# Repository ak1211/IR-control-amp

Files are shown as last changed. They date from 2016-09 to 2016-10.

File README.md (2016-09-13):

# IR-control-amp

## Overview
Infra Red remote control amplifier firmware on atmega328p

## Description
このソフトウエアはatmega328p使用  
赤外線リモコンコントロールヘッドホンアンプ基板Rev: A2.x用  
組込みファームウエアです。

## Requirements
Atmel Studio 7 (Version: 7.0.594 - )
© 2015 Atmel Corp.
All rights reserved.

## Compile and Link
Atmel Studio 7で[solution file](https://github.com/ak1211/IR-control-amp/blob/master/AudioAmpApplication/AudioAmpApplication.atsln)
を開いてコンパイル＆リンクを行ってください。

## License
[MIT](https://github.com/ak1211/IR-control-amp/blob/master/LICENSE)

## Author
[ak1211](https://github.com/ak1211/) - [blog](https://ak1211.com/index.php)

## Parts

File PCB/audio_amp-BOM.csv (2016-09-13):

Reference | Value | Footprint | Datasheet
L1 | 220u | Choke_SMD:Choke_SMD_10.4x10.4_H4.8
L2 | 220u | Choke_SMD:Choke_SMD_10.4x10.4_H4.8
U1 | NJU7223DL1 | Transistors_SMD:sot428
F1 | PolySW 1.85A | Fuse_Holders_and_Fuses:Fuse_TE5_Littlefuse-395Series
CON1 | BARREL_JACK | Connect:BARREL_JACK
U3 | FDS4935 | Housings_SOIC:SOIC-8_3.9x4.9mm_Pitch1.27mm
U2 | NDS9936 | Housings_SOIC:SOIC-8_3.9x4.9mm_Pitch1.27mm
U4 | MCWI03_12D05 | mylib:MINMAX_MCWI03-12x
Q1 | 2SK2411 | Transistors_SMD:sot404
C3 | 8200u | Capacitors_ThroughHole:C_Radial_D18_L36_P7.5
C1 | 220u | Capacitors_SMD:c_elec_10x10.5
C2 | 47u | Capacitors_SMD:c_elec_10x10.5
C4 | 22u(tantalum) | Capacitors_Tantalum_SMD:TantalC_SizeA_EIA-3216_HandSoldering
C5 | 22u(tantalum) | Capacitors_Tantalum_SMD:TantalC_SizeA_EIA-3216_HandSoldering
C6 | 22u(tantalum) | Capacitors_Tantalum_SMD:TantalC_SizeA_EIA-3216_HandSoldering
C7 | 22u(tantalum) | Capacitors_Tantalum_SMD:TantalC_SizeA_EIA-3216_HandSoldering
D1 | LED | LEDs:LED-0805
P1 | AMP_POWER | Sockets_MOLEX_KK-System:Socket_MOLEX-KK-RM3-96mm_Lock_2pin_straight
R1 | 10 | Resistors_SMD:R_0805_HandSoldering
R2 | 10k | Resistors_SMD:R_0805_HandSoldering
R3 | 33k | Resistors_SMD:R_0805_HandSoldering
R4 | 33(2W) | Resistors_ThroughHole:Resistor_Horizontal_RM20mm
R5 | 10 | Resistors_SMD:R_0805_HandSoldering
R6 | 10k | Resistors_SMD:R_0805_HandSoldering
R7 | 33k | Resistors_SMD:R_0805_HandSoldering
R8 | 4.7k | Resistors_SMD:R_0805_HandSoldering
C30 | 22u(tantalum) | Capacitors_Tantalum_SMD:TantalC_SizeA_EIA-3216_HandSoldering
C29 | 22u(tantalum) | Capacitors_Tantalum_SMD:TantalC_SizeA_EIA-3216_HandSoldering
C32 | 0.1u | Capacitors_SMD:C_0805_HandSoldering
C31 | 0.1u | Capacitors_SMD:C_0805_HandSoldering
C33 | 0.1u | Capacitors_SMD:C_0805_HandSoldering
U10 | NDS9936 | Housings_SOIC:SOIC-8_3.9x4.9mm_Pitch1.27mm
R46 | 33k | Resistors_SMD:R_0805_HandSoldering
U8 | LME49600 | mylib:LME49600
J3 | PHONE OUT | toragi_201305:AJ-1780
J1 | 1ch IN | toragi_201305:AJ-1780
J2 | 2ch IN | toragi_201305:AJ-1780
U7 | LM1972 | Housings_SOIC:SOIC-20_7.5x12.8mm_Pitch1.27mm
C22 | 0.1u | Capacitors_SMD:C_0805_HandSoldering
C15 | 1u(film) | Capacitors_SMD:C_1206_HandSoldering
C16 | 1u(film) | Capacitors_SMD:C_1206_HandSoldering
U9 | LME49600 | mylib:LME49600
C18 | 1u(film) | Capacitors_SMD:C_1206_HandSoldering
C19 | 1u(film) | Capacitors_SMD:C_1206_HandSoldering
C14 | 1u(film) | Capacitors_SMD:C_1206_HandSoldering
C8 | 1u(film) | Capacitors_SMD:C_1206_HandSoldering
C9 | 1u(film) | Capacitors_SMD:C_1206_HandSoldering
C17 | 1u(film) | Capacitors_SMD:C_1206_HandSoldering
C12 | 1u(film) | Capacitors_SMD:C_1206_HandSoldering
C13 | 1u(film) | Capacitors_SMD:C_1206_HandSoldering
C20 | 1u(film) | Capacitors_SMD:C_1206_HandSoldering
C21 | 1u(film) | Capacitors_SMD:C_1206_HandSoldering
G1 | GND_SUMMING_PT | mylib:GND_SUMMING_PT
C11 | open | Capacitors_SMD:C_1206_HandSoldering
C10 | open | Capacitors_SMD:C_1206_HandSoldering
D2 | 02CZ3.3(3.3V) | mylib_legacy:SC-59
D3 | 02CZ3.3(3.3V) | mylib_legacy:SC-59
P2 | OUT ch.L | Sockets_MOLEX_KK-System:Socket_MOLEX-KK-RM2-54mm_Lock_2pin_straight
P3 | OUT ch.R | Sockets_MOLEX_KK-System:Socket_MOLEX-KK-RM2-54mm_Lock_2pin_straight
R9 | open | Resistors_SMD:R_0805_HandSoldering
R10 | open | Resistors_SMD:R_0805_HandSoldering
R18 | 100k | Resistors_SMD:R_0805_HandSoldering
R22 | 10 | Resistors_SMD:R_0805_HandSoldering
R23 | 10k | Resistors_SMD:R_0805_HandSoldering
R24 | 10k | Resistors_SMD:R_0805_HandSoldering
R26 | 10k | Resistors_SMD:R_0805_HandSoldering
R25 | 10k | Resistors_SMD:R_0805_HandSoldering
R27 | 10k | Resistors_SMD:R_0805_HandSoldering
R11 | 1k | Resistors_SMD:R_0805_HandSoldering
R21 | 1k | Resistors_SMD:R_0805_HandSoldering
R19 | 1k | Resistors_SMD:R_0805_HandSoldering
R13 | 1M | Resistors_SMD:R_0805_HandSoldering
R14 | 1M | Resistors_SMD:R_0805_HandSoldering
R20 | 1k | Resistors_SMD:R_0805_HandSoldering
R17 | 1k | Resistors_SMD:R_0805_HandSoldering
R12 | 1k | Resistors_SMD:R_0805_HandSoldering
R15 | 1M | Resistors_SMD:R_0805_HandSoldering
R16 | 1M | Resistors_SMD:R_0805_HandSoldering
D4 | 1N4148W1 | Diodes_SMD:SOD-123
D5 | 1N4148W1 | Diodes_SMD:SOD-123
D6 | 1N4148W1 | Diodes_SMD:SOD-123
inputRLY1 | G5V2 | mylib:G5V-2
C27 | 1u(film) | Capacitors_SMD:C_1206_HandSoldering
C28 | 1u(film) | Capacitors_SMD:C_1206_HandSoldering
JP2 | Jumper_NC_Small | Connect:GS2
JP3 | Jumper_NC_Small | Connect:GS2
U11 | LMC6482
U5 | LME49720
U6 | LME49720
Q2 | 8MHz | mylib:CERALOCK
U14 | PL-IRM2161 | mylib:PL-IRM2161
U18 | SO1602AWYB-UC-WB | Display:WC1602A
RE1 | R_ENC_SW_RGB_LED | mylib:EC12PLRGBSDHF
U13 | NDS9936 | Housings_SOIC:SOIC-8_3.9x4.9mm_Pitch1.27mm
U12 | NDS9936 | Housings_SOIC:SOIC-8_3.9x4.9mm_Pitch1.27mm
U17 | FDS4935 | Housings_SOIC:SOIC-8_3.9x4.9mm_Pitch1.27mm
C23 | 0.1u | Capacitors_SMD:C_0805_HandSoldering
C24 | 0.1u | Capacitors_SMD:C_0805_HandSoldering
C26 | 2.2u | Capacitors_SMD:C_1206_HandSoldering
U15 | TLP121 | Opto-Devices:Optocoupler_SMD_HandSoldering_KPC357_LTV35x_PC357_SingleChannel
U16 | TLP121 | Opto-Devices:Optocoupler_SMD_HandSoldering_KPC357_LTV35x_PC357_SingleChannel
IC1 | ATMEGA328P-P | Housings_DIP:DIP-28_W7.62mm_LongPads
P4 | AVRISP | mylib:AVRISP_Angled
SW1 | RESET | mylib:ALPS_TACT_SW_SKHHL
P7 | STBY | Sockets_MOLEX_KK-System:Socket_MOLEX-KK-RM2-54mm_Lock_3pin_straight
P8 | MUTE | Sockets_MOLEX_KK-System:Socket_MOLEX-KK-RM2-54mm_Lock_3pin_straight
P5 | DISPLAY | Sockets_MOLEX_KK-System:Socket_MOLEX-KK-RM2-54mm_Lock_4pin_straight
P6 | CONN_01X04 | Sockets_MOLEX_KK-System:Socket_MOLEX-KK-RM2-54mm_Lock_4pin_straight
R28 | 1k | Resistors_SMD:R_0805_HandSoldering
R31 | 1k | Resistors_SMD:R_0805_HandSoldering
R34 | 1.2k | Resistors_SMD:R_0805_HandSoldering
R29 | 10k | Resistors_SMD:R_0805_HandSoldering
R30 | 10 | Resistors_SMD:R_0805_HandSoldering
R32 | 10k | Resistors_SMD:R_0805_HandSoldering
R33 | 10 | Resistors_SMD:R_0805_HandSoldering
R35 | 10k | Resistors_SMD:R_0805_HandSoldering
R36 | 10 | Resistors_SMD:R_0805_HandSoldering
R37 | 10k | Resistors_SMD:R_0805_HandSoldering
R40 | 330 | Resistors_SMD:R_0805_HandSoldering
R41 | 330 | Resistors_SMD:R_0805_HandSoldering
R44 | 10k | Resistors_SMD:R_0805_HandSoldering
R45 | 10k | Resistors_SMD:R_0805_HandSoldering
R43 | 10k | Resistors_SMD:R_0805_HandSoldering
R42 | 10 | Resistors_SMD:R_0805_HandSoldering
R38 | 4.7k | Resistors_SMD:R_0805_HandSoldering
R39 | 4.7k | Resistors_SMD:R_0805_HandSoldering
C25 | 0.1u | Capacitors_SMD:C_0805_HandSoldering

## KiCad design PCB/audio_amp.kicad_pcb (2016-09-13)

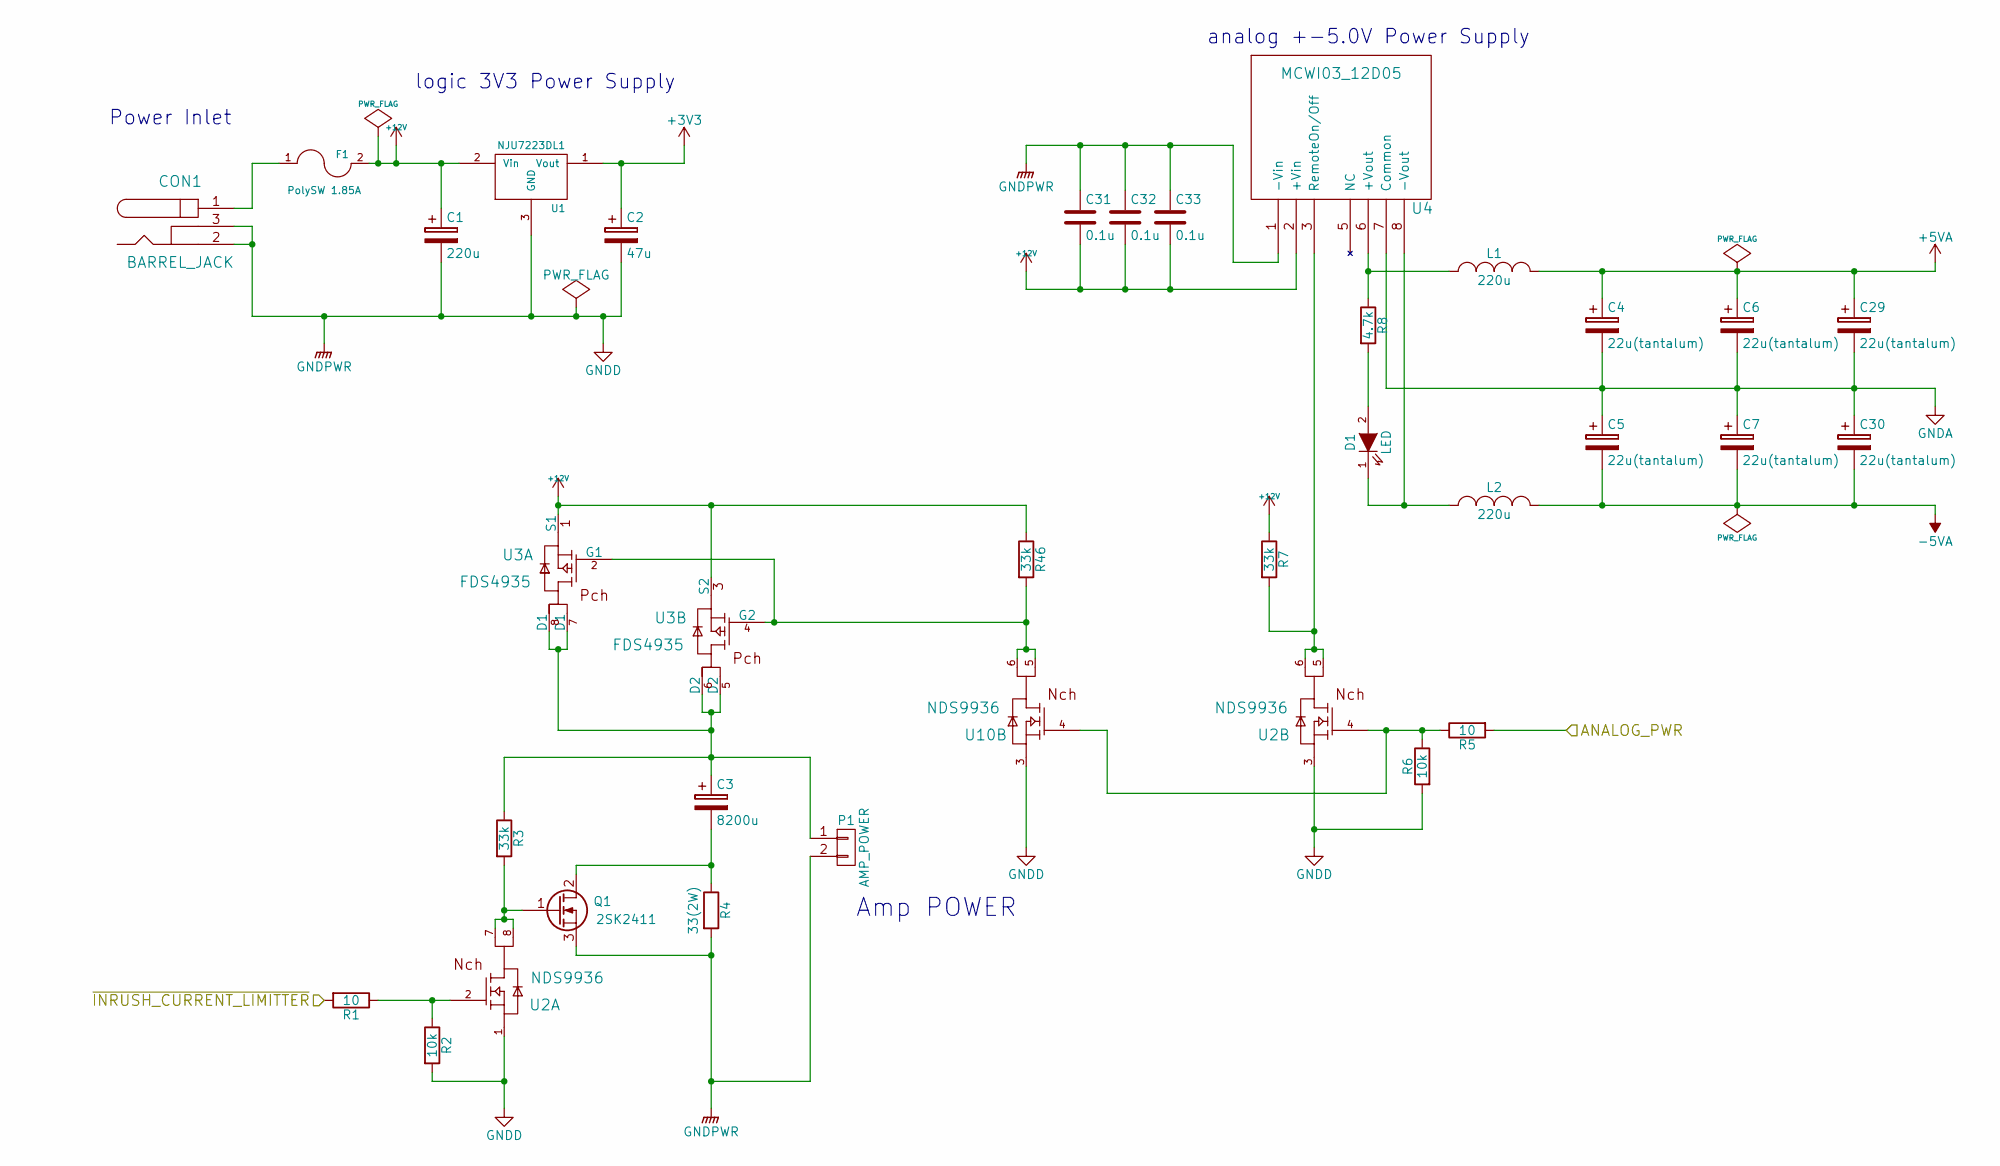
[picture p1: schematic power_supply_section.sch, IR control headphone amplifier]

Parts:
C1: 220u; c_elec_10x10.5
C2: 47u; c_elec_10x10.5
C3: 8200u; C_Radial_D18_L36_P7.5
C4, C5, C6, C7, C29, C30: 22u(tantalum); TantalC_SizeA_EIA-3216_HandSoldering
C31, C32, C33: 0.1u; C_0805_HandSoldering
CON1: BARREL_JACK
D1: LED; LED-0805
F1: PolySW 1.85A; Fuse_TE5_Littlefuse-395Series
L1, L2: 220u; Choke_SMD_10.4x10.4_H4.8
P1: AMP_POWER; Socket_MOLEX-KK-RM3-96mm_Lock_2pin_straight
Q1: 2SK2411; sot404
R1, R5: 10; R_0805_HandSoldering
R2, R6: 10k; R_0805_HandSoldering
R3, R7, R46: 33k; R_0805_HandSoldering
R4: 33(2W); Resistor_Horizontal_RM20mm
R8: 4.7k; R_0805_HandSoldering
U1: NJU7223DL1; sot428
U2, U10: NDS9936; SOIC-8_3.9x4.9mm_Pitch1.27mm
U3: FDS4935; SOIC-8_3.9x4.9mm_Pitch1.27mm
U4: MCWI03_12D05; MINMAX_MCWI03-12x

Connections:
+3V3: C2.1, U1.1 (Vout); also elsewhere on the board
+5VA: C4.1, C6.1, C29.1, L1.2; also elsewhere on the board
+12V: C1.1, C31.2, C32.2, C33.2, F1.2, R7.1, R46.1, U1.2 (Vin), U3.1 (S1), U3.3 (S2), U4.2 (+Vin); also elsewhere on the board
-5VA: C5.2, C7.2, C30.2, L2.2; also elsewhere on the board
/controller_section/ANALOG_PWR: R5.2; also elsewhere on the board
/controller_section/~INRUSH_CURRENT_LIMITTER: R1.2; also elsewhere on the board
GNDA: C4.2, C5.1, C6.2, C7.1, C29.2, C30.1, U4.7 (Common); also elsewhere on the board
GNDD: C1.2, C2.2, C31.1, C32.1, C33.1, CON1.2, CON1.3, P1.2, Q1.3 (S), R2.2, R4.2, R6.2, U1.3 (GND), U2.1, U2.3, U4.1 (-Vin), U10.3; also elsewhere on the board
unnamed: C3.1, P1.1, R3.1, U3.5 (D2), U3.6 (D2), U3.7 (D1), U3.8 (D1)
unnamed: C3.2, Q1.2 (D), R4.1
unnamed: CON1.1, F1.1
unnamed: D1.1 (K), L2.1, U4.8 (-Vout)
unnamed: D1.2 (A), R8.2
unnamed: L1.1, R8.1, U4.6 (+Vout)
unnamed: Q1.1 (G), R3.2, U2.7, U2.8
unnamed: R1.1, R2.1, U2.2
unnamed: R5.1, R6.1, U2.4, U10.4
unnamed: R7.2, U2.5, U2.6, U4.3 (RemoteOn/Off)
unnamed: R46.2, U3.2 (G1), U3.4 (G2), U10.5, U10.6

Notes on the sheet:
analog +-5.0V Power Supply
Power Inlet
logic 3V3 Power Supply
Amp POWER

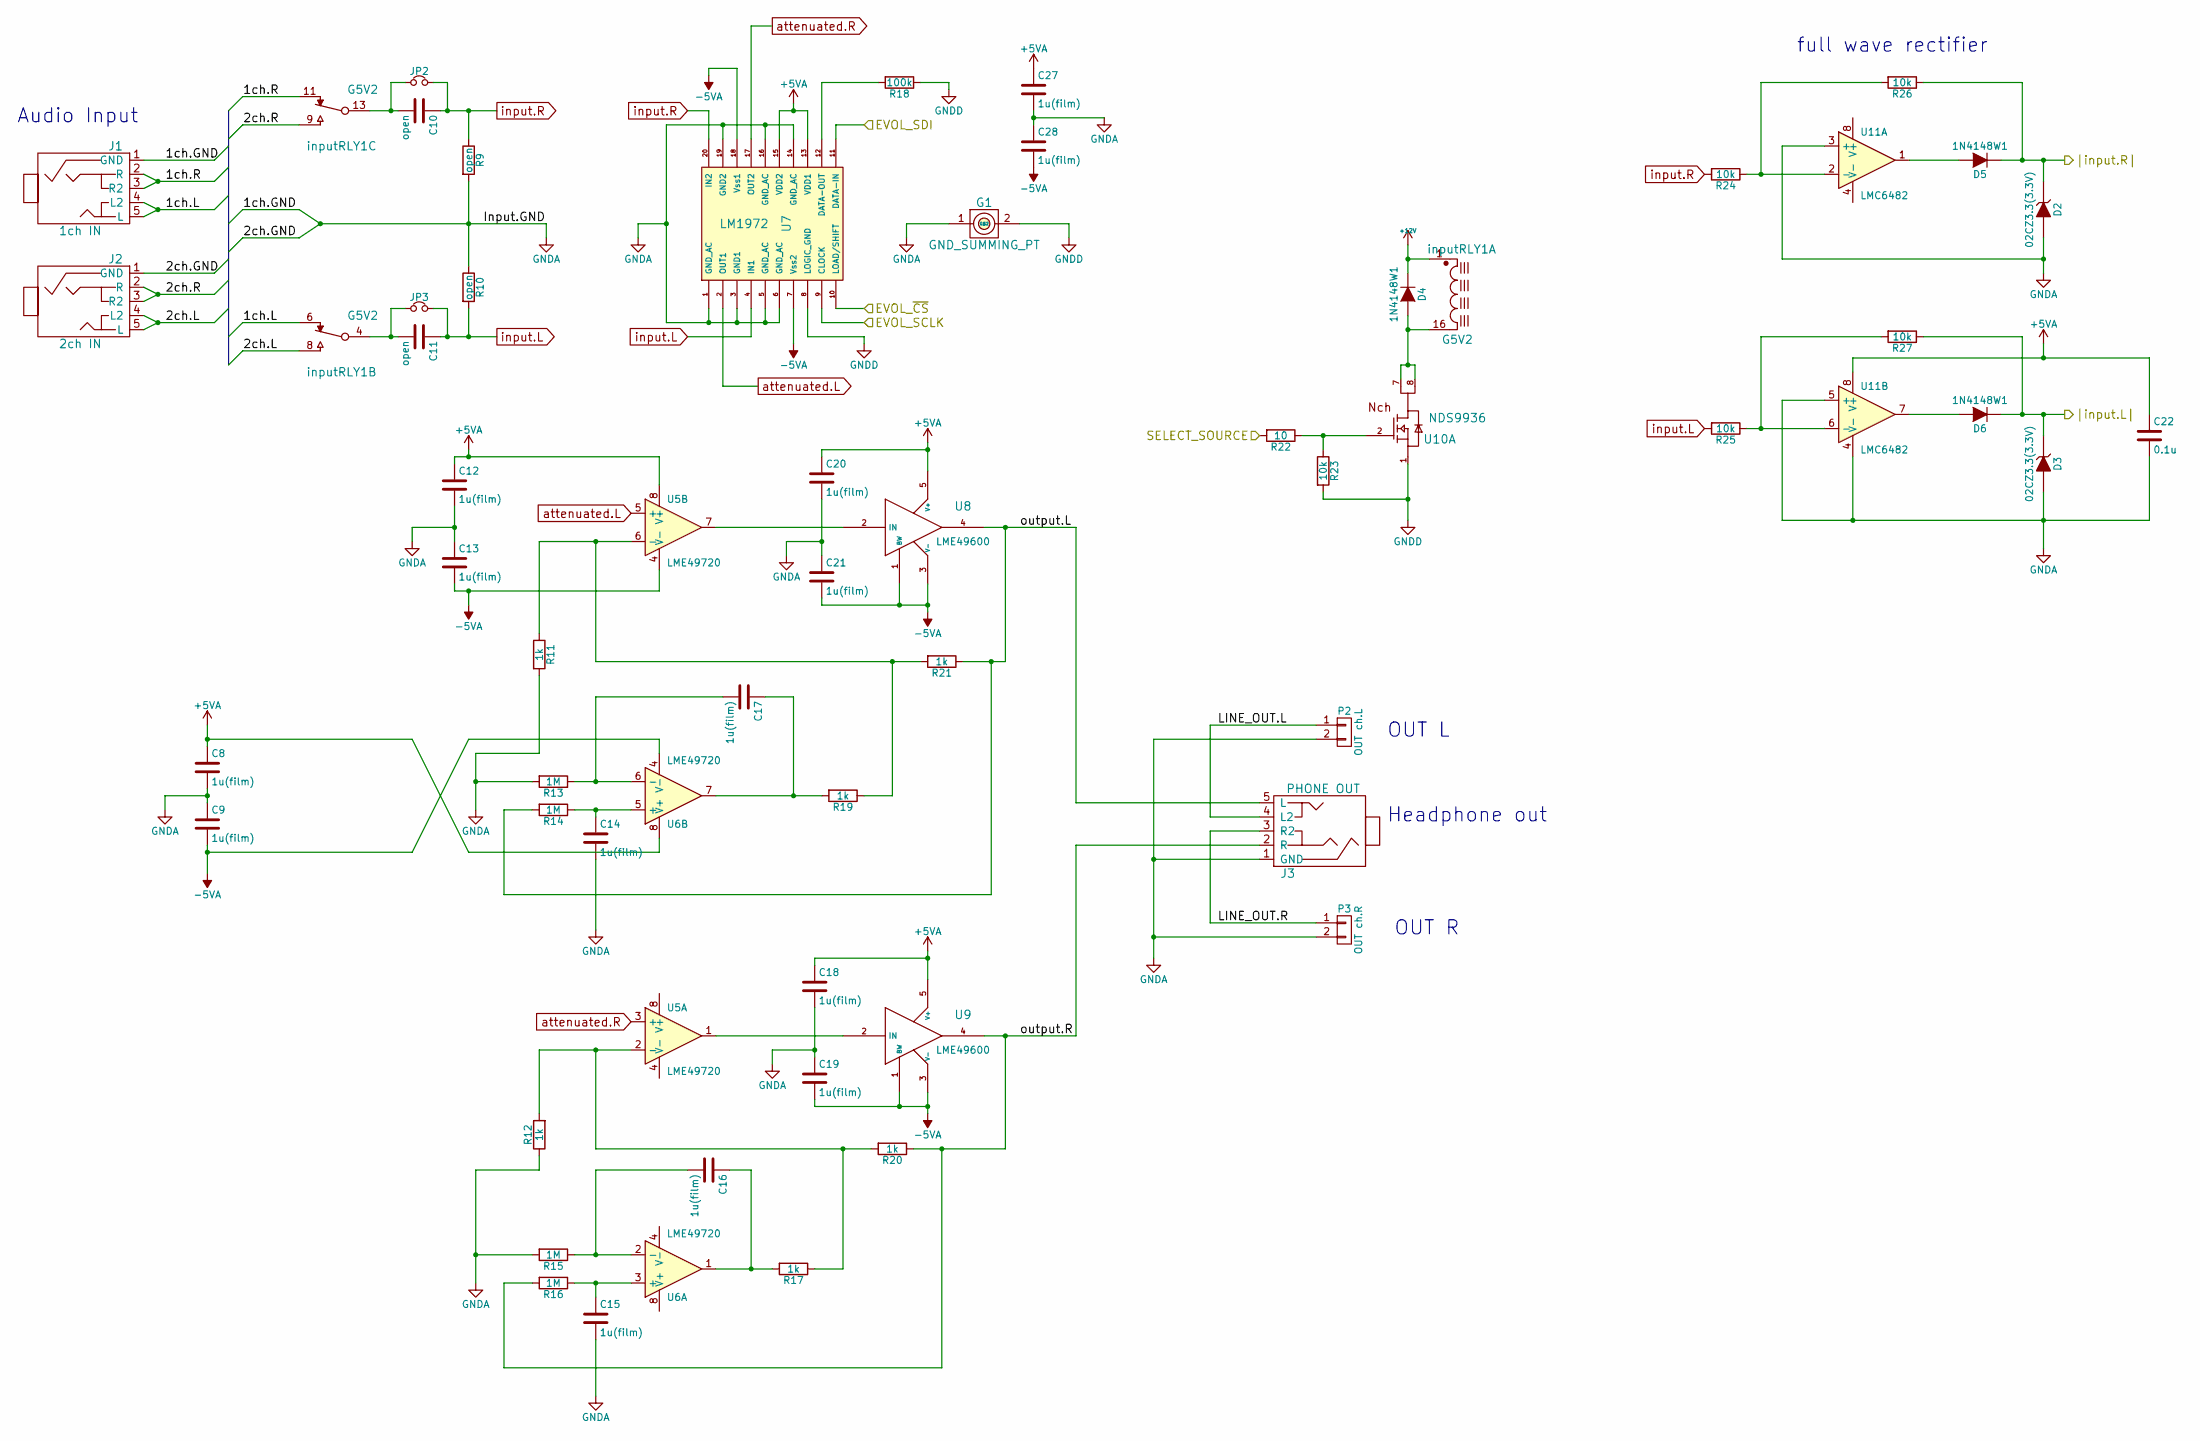
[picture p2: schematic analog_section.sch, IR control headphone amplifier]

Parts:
C8, C9, C12, C13, C14, C15, C16, C17, C18, C19, C20, C21, C27, C28: 1u(film); C_1206_HandSoldering
C10, C11: open; C_1206_HandSoldering
C22: 0.1u; C_0805_HandSoldering
D2, D3: 02CZ3.3(3.3V); SC-59
D4, D5, D6: 1N4148W1; SOD-123
G1: GND_SUMMING_PT
J1: 1ch IN; AJ-1780
J2: 2ch IN; AJ-1780
J3: PHONE OUT; AJ-1780
JP2, JP3: Jumper_NC_Small; GS2
P2: OUT ch.L; Socket_MOLEX-KK-RM2-54mm_Lock_2pin_straight
P3: OUT ch.R; Socket_MOLEX-KK-RM2-54mm_Lock_2pin_straight
R9, R10: open; R_0805_HandSoldering
R11, R12, R17, R19, R20, R21: 1k; R_0805_HandSoldering
R13, R14, R15, R16: 1M; R_0805_HandSoldering
R18: 100k; R_0805_HandSoldering
R22: 10; R_0805_HandSoldering
R23, R24, R25, R26, R27: 10k; R_0805_HandSoldering
U5, U6: LME49720
U7: LM1972; SOIC-20_7.5x12.8mm_Pitch1.27mm
U8, U9: LME49600
U10: NDS9936; SOIC-8_3.9x4.9mm_Pitch1.27mm
U11: LMC6482
inputRLY1: G5V2; G5V-2

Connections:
+5VA: C8.1, C12.1, C18.1, C20.1, C22.1, C27.1, U5.8 (V+), U6.8 (V+), U7.13 (VDD1), U7.15 (VDD2), U8.5 (V+), U9.5 (V+), U11.8 (V+); also elsewhere on the board
+12V: D4.1 (K), inputRLY1.1; also elsewhere on the board
-5VA: C9.2, C13.2, C19.2, C21.2, C28.2, U5.4 (V-), U6.4 (V-), U7.7 (Vss2), U7.18 (Vss1), U8.1 (BW), U8.3 (V-), U9.1 (BW), U9.3 (V-); also elsewhere on the board
/analog_section/1ch.L: J1.4 (L2), J1.5 (L), inputRLY1.6
/analog_section/1ch.R: J1.2 (R), J1.3 (R2), inputRLY1.11
/analog_section/2ch.L: J2.4 (L2), J2.5 (L), inputRLY1.8
/analog_section/2ch.R: J2.2 (R), J2.3 (R2), inputRLY1.9
/analog_section/EVOL_SCLK: U7.9 (CLOCK); also elsewhere on the board
/analog_section/EVOL_SDI: U7.11 (DATA-IN); also elsewhere on the board
/analog_section/EVOL_~CS: U7.10 (LOAD/SHIFT); also elsewhere on the board
/analog_section/LINE_OUT.L: J3.4 (L2), P2.1
/analog_section/LINE_OUT.R: J3.3 (R2), P3.1
/analog_section/SELECT_SOURCE: R22.2; also elsewhere on the board
/analog_section/output.L: J3.5 (L), R14.2, R21.1, U8.4
/analog_section/output.R: J3.2 (R), R16.2, R20.1, U9.4
/analog_section/|input.L|: D3.1 (K), D6.1 (K), R27.1; also elsewhere on the board
/analog_section/|input.R|: D2.1 (K), D5.1 (K), R26.1; also elsewhere on the board
GNDA: C8.2, C9.1, C12.2, C13.1, C14.2, C15.2, C18.2, C19.1, C20.2, C21.1, C22.2, C27.2, C28.1, D2.2 (A), D3.2 (A), G1.1 (G1), J1.1 (GND), J2.1 (GND), J3.1 (GND), P2.2, P3.2, R9.2, R10.1, R11.2, R12.1, R13.2, R15.2, U7.1 (GND_AC), U7.3 (GND1), U7.5 (GND_AC), U7.6 (GND_AC), U7.14 (GND_AC), U7.16 (GND_AC), U7.19 (GND2), U11.3 (+), U11.4 (V-), U11.5 (+); also elsewhere on the board
GNDD: G1.2 (G2), R18.1, R23.2, U7.8 (LOGIC_GND), U10.1; also elsewhere on the board
unnamed: C10.2, JP2.1, inputRLY1.13
unnamed: C11.2, JP3.1, inputRLY1.4
unnamed: C14.1, R14.1, U6.5 (+)
unnamed: C15.1, R16.1, U6.3 (+)
unnamed: C16.1, R17.2, U6.1
unnamed: C16.2, R15.1, U6.2 (-)
unnamed: C17.1, R19.2, U6.7
unnamed: C17.2, R13.1, U6.6 (-)
unnamed: D4.2 (A), U10.7, U10.8, inputRLY1.16
unnamed: D5.2 (A), U11.1
unnamed: D6.2 (A), U11.7
unnamed: R11.1, R19.1, R21.2, U5.6 (-)
unnamed: R12.2, R17.1, R20.2, U5.2 (-)
unnamed: R18.2, U7.12 (DATA-OUT)
unnamed: R22.1, R23.1, U10.2
unnamed: R24.1, R26.2, U11.2 (-)
unnamed: R25.1, R27.2, U11.6 (-)
unnamed: U5.1, U9.2 (IN)
unnamed: U5.7, U8.2 (IN)
attenuated.L: U5.5 (+), U7.2 (OUT1)
attenuated.R: U5.3 (+), U7.17 (OUT2)
input.L: C11.1, JP3.2, R10.2, R25.2, U7.4 (IN1)
input.R: C10.1, JP2.2, R9.1, R24.2, U7.20 (IN2)

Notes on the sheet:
OUT R
Audio Input
Headphone out
full wave rectifier
OUT L

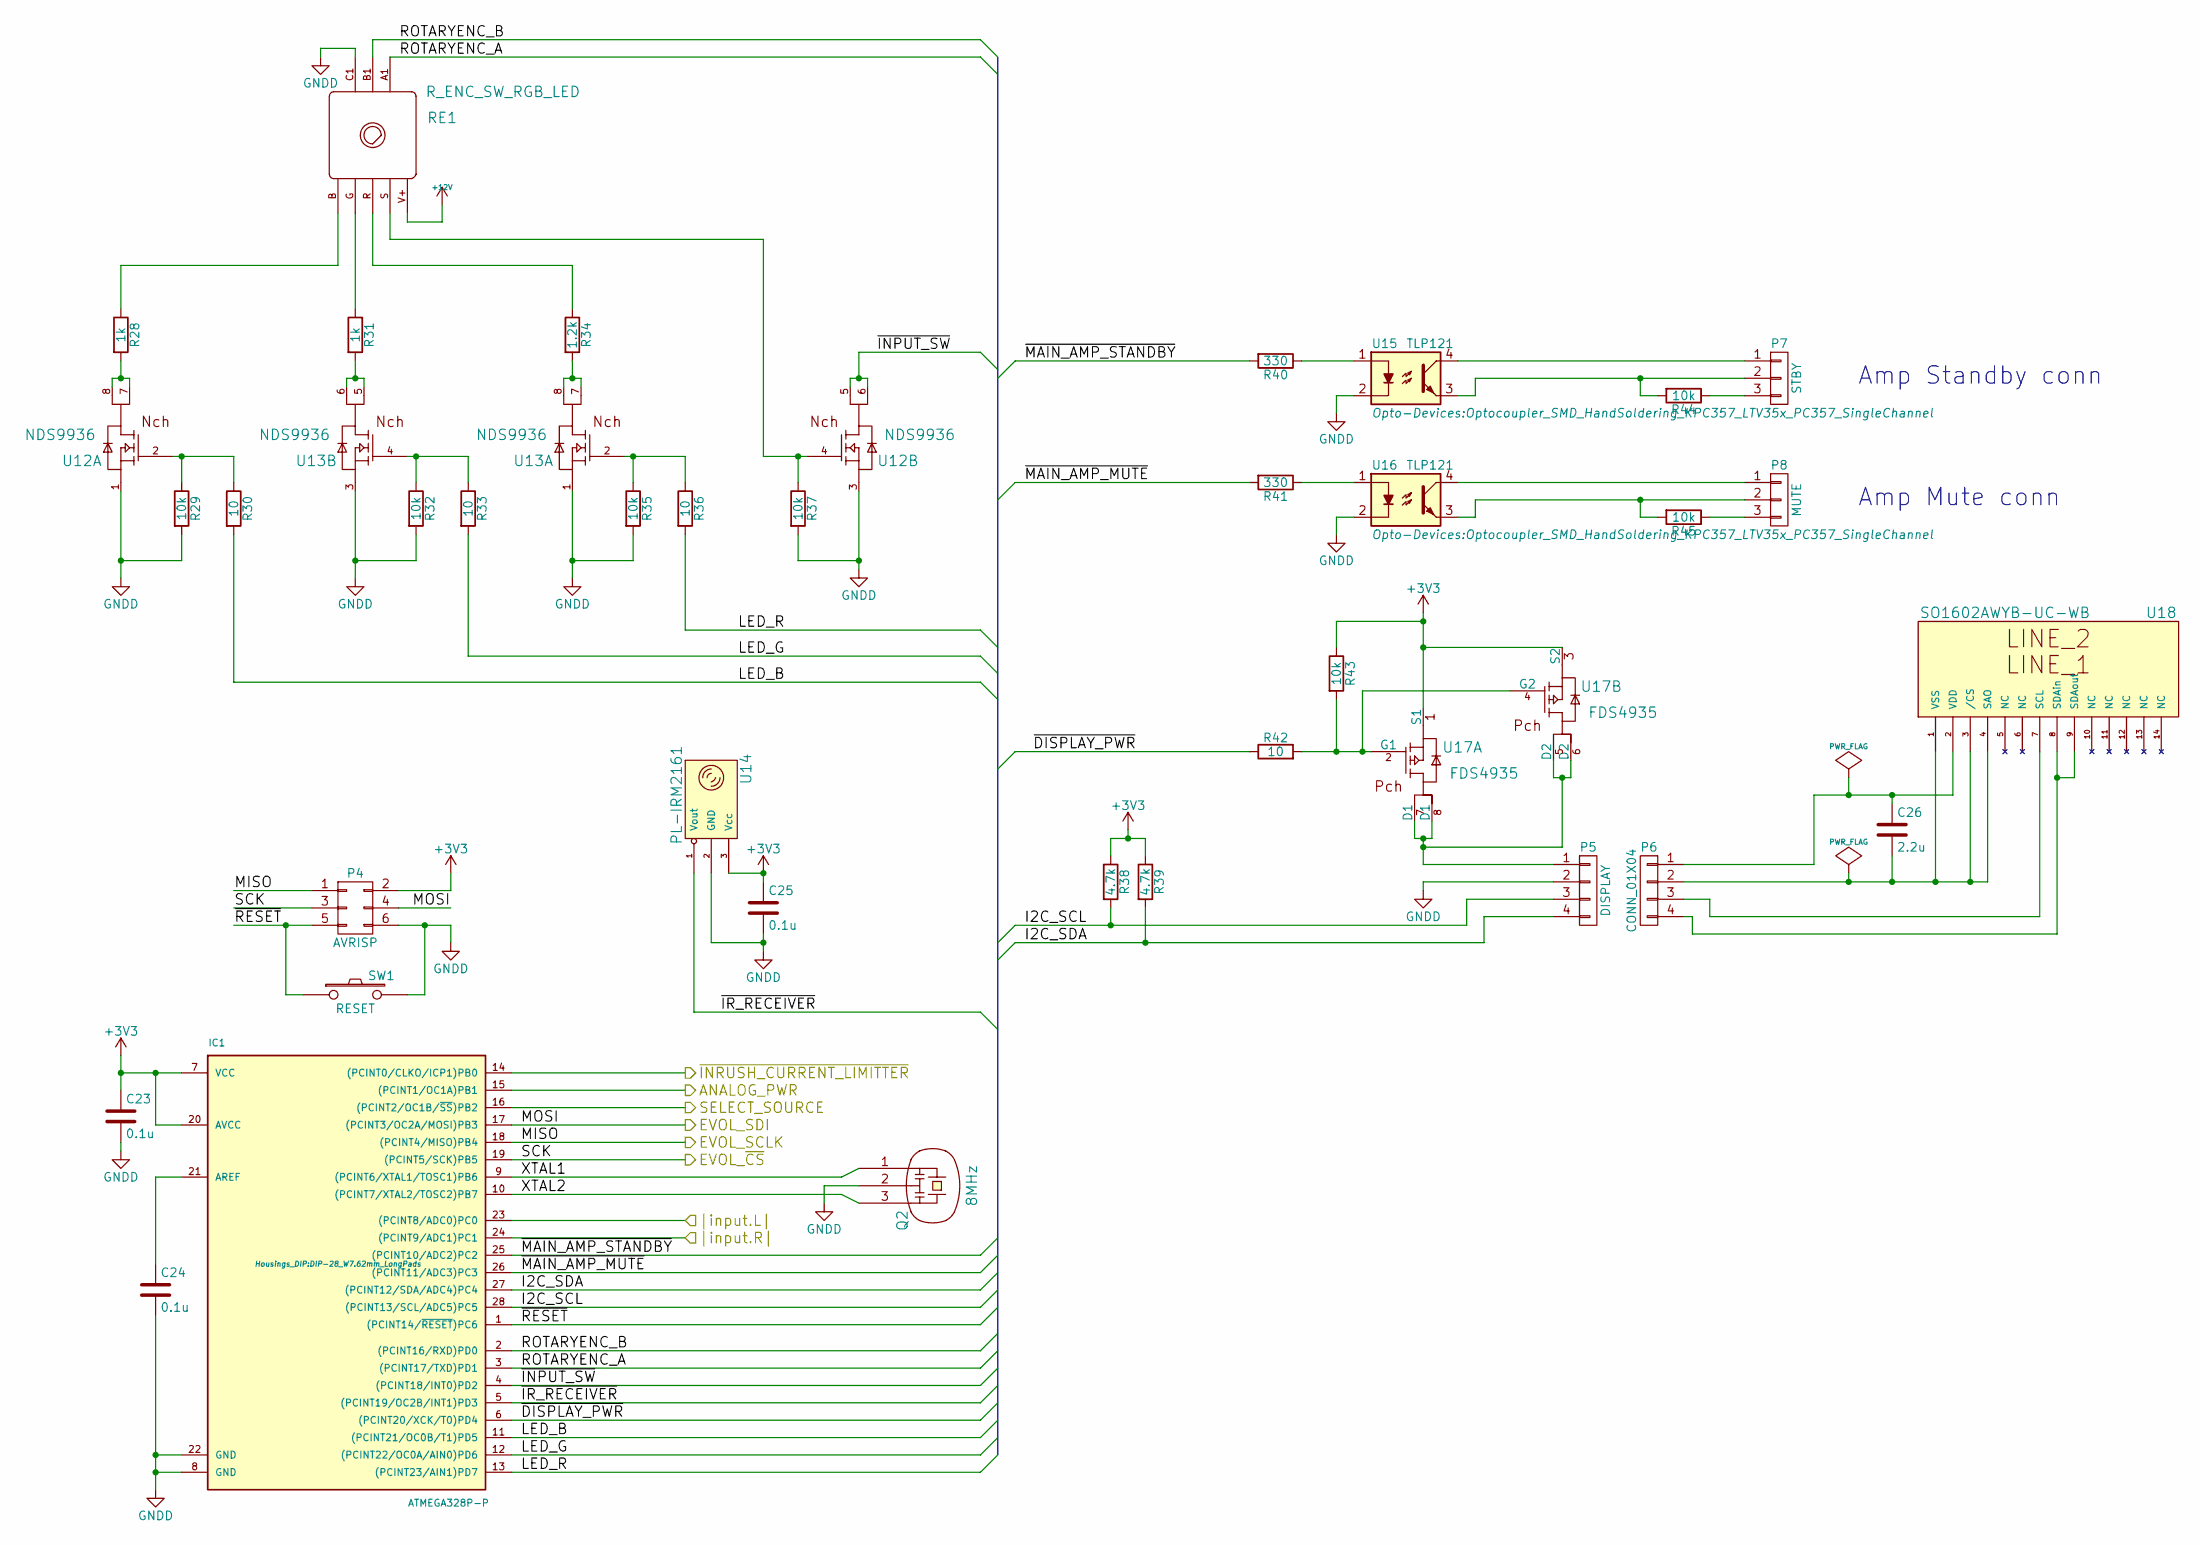
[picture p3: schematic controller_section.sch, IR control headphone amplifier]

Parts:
C23, C24, C25: 0.1u; C_0805_HandSoldering
C26: 2.2u; C_1206_HandSoldering
IC1: ATMEGA328P-P; DIP-28_W7.62mm_LongPads
P4: AVRISP; AVRISP_Angled
P5: DISPLAY; Socket_MOLEX-KK-RM2-54mm_Lock_4pin_straight
P6: CONN_01X04; Socket_MOLEX-KK-RM2-54mm_Lock_4pin_straight
P7: STBY; Socket_MOLEX-KK-RM2-54mm_Lock_3pin_straight
P8: MUTE; Socket_MOLEX-KK-RM2-54mm_Lock_3pin_straight
Q2: 8MHz; CERALOCK
R28, R31: 1k; R_0805_HandSoldering
R29, R32, R35, R37, R43, R44, R45: 10k; R_0805_HandSoldering
R30, R33, R36, R42: 10; R_0805_HandSoldering
R34: 1.2k; R_0805_HandSoldering
R38, R39: 4.7k; R_0805_HandSoldering
R40, R41: 330; R_0805_HandSoldering
RE1: R_ENC_SW_RGB_LED; EC12PLRGBSDHF
SW1: RESET; ALPS_TACT_SW_SKHHL
U12, U13: NDS9936; SOIC-8_3.9x4.9mm_Pitch1.27mm
U14: PL-IRM2161
U15, U16: TLP121; Optocoupler_SMD_HandSoldering_KPC357_LTV35x_PC357_SingleCha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
U17: FDS4935; SOIC-8_3.9x4.9mm_Pitch1.27mm
U18: SO1602AWYB-UC-WB; WC1602A

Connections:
+3V3: C23.1, C25.1, IC1.7 (VCC), IC1.20 (AVCC), P4.2, R38.1, R39.1, R43.1, U14.3 (Vcc), U17.1 (S1), U17.3 (S2); also elsewhere on the board
+12V: RE1.V+; also elsewhere on the board
/analog_section/EVOL_SCLK: IC1.18 ((PCINT4/MISO)PB4), P4.1; also elsewhere on the board
/analog_section/EVOL_SDI: IC1.17 ((PCINT3/OC2A/MOSI)PB3), P4.4; also elsewhere on the board
/analog_section/EVOL_~CS: IC1.19 ((PCINT5/SCK)PB5), P4.3; also elsewhere on the board
/analog_section/SELECT_SOURCE: IC1.16 ((PCINT2/OC1B/~SS~)PB2); also elsewhere on the board
/analog_section/|input.L|: IC1.23 ((PCINT8/ADC0)PC0); also elsewhere on the board
/analog_section/|input.R|: IC1.24 ((PCINT9/ADC1)PC1); also elsewhere on the board
/controller_section/ANALOG_PWR: IC1.15 ((PCINT1/OC1A)PB1); also elsewhere on the board
/controller_section/I2C_SCL: IC1.28 ((PCINT13/SCL/ADC5)PC5), P5.3, R38.2
/controller_section/I2C_SDA: IC1.27 ((PCINT12/SDA/ADC4)PC4), P5.4, R39.2
/controller_section/LED_B: IC1.11 ((PCINT21/OC0B/T1)PD5), R30.2
/controller_section/LED_G: IC1.12 ((PCINT22/OC0A/AIN0)PD6), R33.2
/controller_section/LED_R: IC1.13 ((PCINT23/AIN1)PD7), R36.2
/controller_section/ROTARYENC_A: IC1.3 ((PCINT17/TXD)PD1), RE1.A1
/controller_section/ROTARYENC_B: IC1.2 ((PCINT16/RXD)PD0), RE1.B1
/controller_section/XTAL1: IC1.9 ((PCINT6/XTAL1/TOSC1)PB6), Q2.1
/controller_section/XTAL2: IC1.10 ((PCINT7/XTAL2/TOSC2)PB7), Q2.3
/controller_section/~DISPLAY_PWR: IC1.6 ((PCINT20/XCK/T0)PD4), R42.1
/controller_section/~INPUT_SW: IC1.4 ((PCINT18/INT0)PD2), U12.5, U12.6
/controller_section/~INRUSH_CURRENT_LIMITTER: IC1.14 ((PCINT0/CLKO/ICP1)PB0); also elsewhere on the board
/controller_section/~IR_RECEIVER: IC1.5 ((PCINT19/OC2B/INT1)PD3), U14.1 (Vout)
/controller_section/~MAIN_AMP_MUTE: IC1.26 ((PCINT11/ADC3)PC3), R41.2
/controller_section/~MAIN_AMP_STANDBY: IC1.25 ((PCINT10/ADC2)PC2), R40.2
/controller_section/~RESET: IC1.1 ((PCINT14/~RESET~)PC6), P4.5, SW1.1
GNDD: C23.2, C24.2, C25.2, IC1.8 (GND), IC1.22 (GND), P4.6, P5.2, Q2.2, R29.2, R32.2, R35.2, R37.2, RE1.C1, SW1.2, U12.1, U12.3, U13.1, U13.3, U14.2 (GND), U15.2, U16.2; also elsewhere on the board
unnamed: C24.1, IC1.21 (AREF)
unnamed: C26.1, P6.1, U18.2 (VDD)
unnamed: C26.2, P6.2, U18.1 (VSS), U18.3 (/CS), U18.4 (SAO)
unnamed: P5.1, U17.5 (D2), U17.6 (D2), U17.7 (D1), U17.8 (D1)
unnamed: P6.3, U18.7 (SCL)
unnamed: P6.4, U18.8 (SDAin), U18.9 (SDAout)
unnamed: P7.1, U15.4
unnamed: P7.2, R44.2, U15.3
unnamed: P7.3, R44.1
unnamed: P8.1, U16.4
unnamed: P8.2, R45.2, U16.3
unnamed: P8.3, R45.1
unnamed: R28.1, RE1.B
unnamed: R28.2, U12.7, U12.8
unnamed: R29.1, R30.1, U12.2
unnamed: R31.1, RE1.G
unnamed: R31.2, U13.5, U13.6
unnamed: R32.1, R33.1, U13.4
unnamed: R34.1, RE1.R
unnamed: R34.2, U13.7, U13.8
unnamed: R35.1, R36.1, U13.2
unnamed: R37.1, RE1.S, U12.4
unnamed: R40.1, U15.1
unnamed: R41.1, U16.1
unnamed: R42.2, R43.2, U17.2 (G1), U17.4 (G2)

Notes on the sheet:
Amp Standby conn
Amp Mute conn

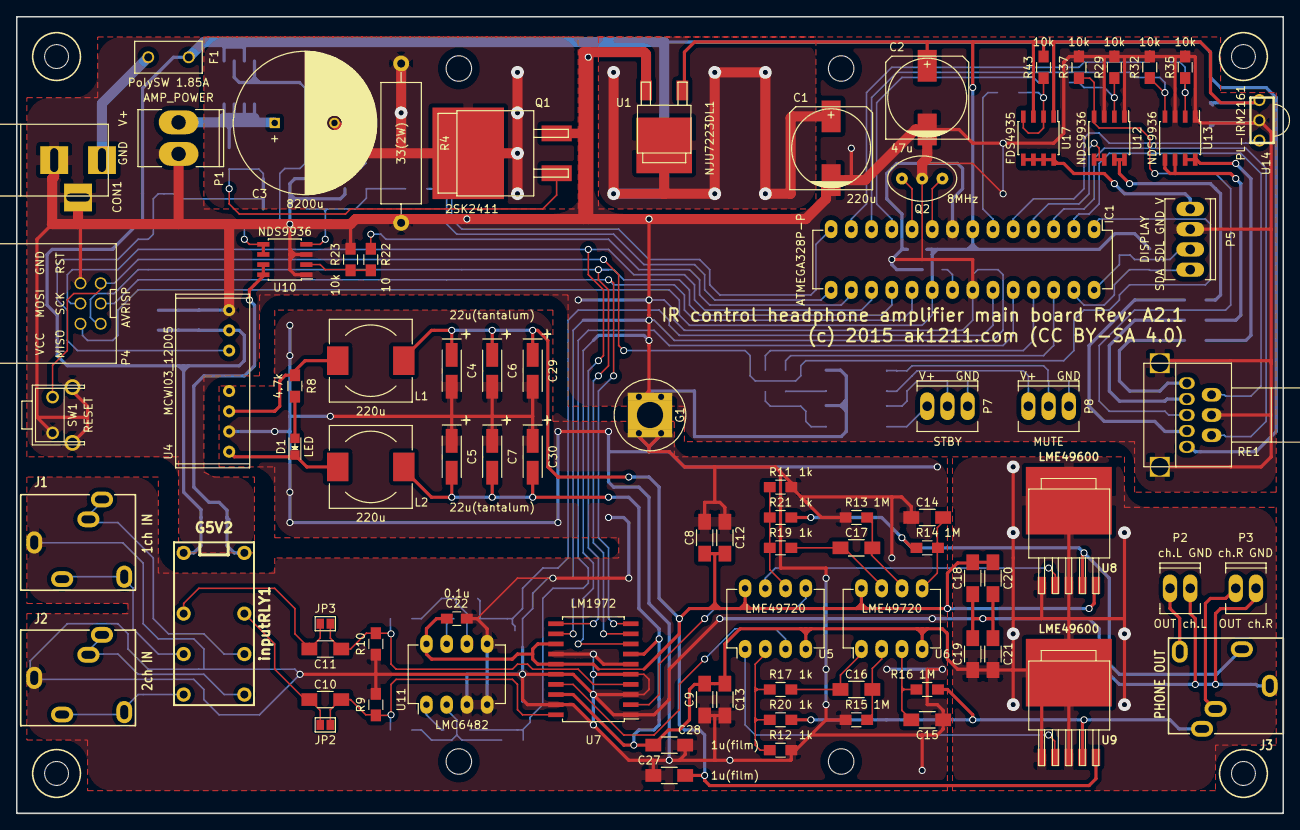
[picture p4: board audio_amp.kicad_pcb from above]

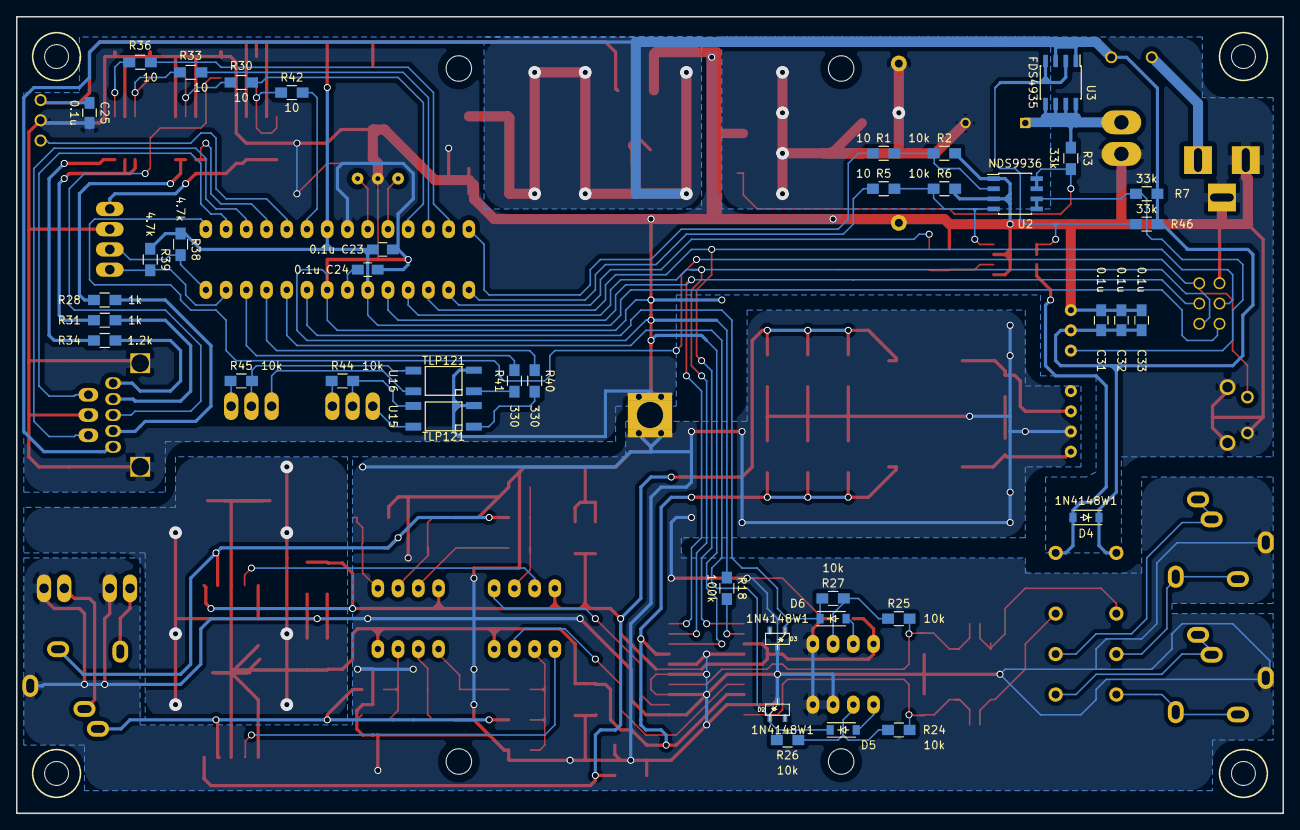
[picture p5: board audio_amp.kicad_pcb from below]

Board: 2 copper layers, 159.0 x 100.0 mm, 128 parts (40 on the bottom side), 92 nets.

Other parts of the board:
hole_m3, hole_m3#2, hole_m3#3, hole_m3#4: P***; hole_m3

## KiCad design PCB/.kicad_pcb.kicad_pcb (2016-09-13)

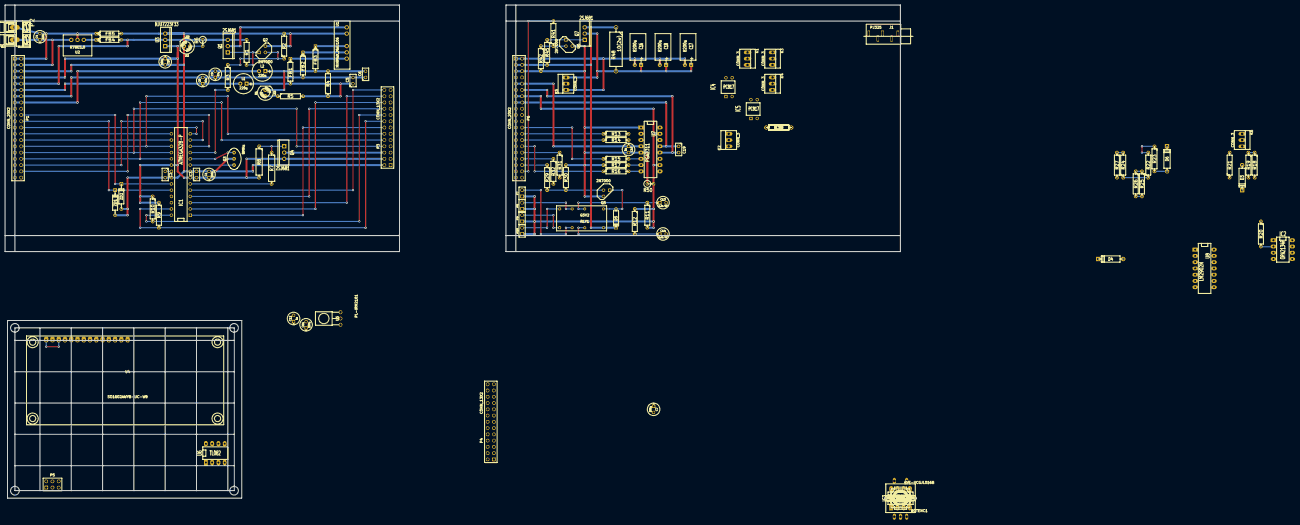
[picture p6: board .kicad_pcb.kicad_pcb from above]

Board: 2 copper layers, 363.2 x 200.0 mm, 125 parts (0 on the bottom side), 102 nets.

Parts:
C1, C7, C10, C11: 100u; C1V5
C2, C3, C5, C6, C19: 0.1u; C1
C4: 220u; C1V5
C8, C9: 47u; C1V5
C12, C15: 1u; C1V5
C13, C14: 2.2u BP; C1V5
C16, C17, C18: 8200u; C1V7H
D1, D2: LED; LED-5MM
D3, D4, D6, D7: DIODE; D4
D5: DIODE; D3
FB1, FB2, FB3, FB4, FB5: FILTER; CP4
IC1: ATMEGA328-P; DIP-28__300
IC2, IC3: OPA2134P; DIP-8__300_ELL
IC4, IC5: PC817; DIP-4__300
J1: PJ325
K1, K2, K3, K4, K5, K6: CONN_3; PINHEAD1-3
L1, L2: 220u; C1V8
P1, P6: CONN_20X2; PIN_ARRAY_20X2
P2: CONN_2; AK300-2
P3, P4: CONN_13X2; pin_array_13x2
P5: CONN_6; pin_array_3x2
P7, P8, P9, P10: CONN_2; PIN_ARRAY_2X1
Q1, Q4, Q7: 2SJ681; TO220_VERTGDS
Q2, Q5, Q6: 2N7000; TO92DGS
Q3: 8MHz; CERALOCK
R1, R2, R30, R38, R39, R42: 10k; R4
R3, R29, R41: 10; R4
R4, R13, R14, R15, R16: 1k; R4
R5, R9, R10, R23, R24, R27, R28: 4.7k; R4
R6: 4.7k; R1
R7: 10; R5
R8: 10k; R5
R11, R12, R17: 47k; R4
R18, R19, R20, R21, R22, R25, R26, R33, R40, R43, R44, R46, R47, R49: 100k; R4
R31, R32: 220; R4
R34, R35, R36, R37: 47; R4
R45: 33k; R4
R48: 10(2w); R7
R50: 0; R1
RLY1: G5V2; G5V-2
ROTENC1: EVE-VCGJL016B; EVEV
SW1: RESET_SW; SW_PUSH_SMALL
U1: MINMAX_MAU106; MAU106
U2: R78E5.0; RECOM_R78E
U3: NJU7223F33; TO220_VERT123
U4: SO1602AWYB-UC-WB; SO1602
U5: PL-IRM2161
U6: TL082; DIP-8__300_ELL
U7: PGA2311; DIP-16__300_ELL
U8: LM2902N; DIP-14__300_ELL
ZD1, ZD2: 3.3V; DO-41

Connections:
+3.3V: C1.1, C3.1, C10.1, C12.1, IC1.7, IC1.20, P1.7, P1.8, P3.4, P4.4, P5.2, P6.7, P6.8, Q4.S, R8.2, R9.1, R10.1, U3.1, U5.3
+5.0V: C8.1, C19.2, IC2.8, IC3.8, L1.2, P1.11, P1.12, P6.11, P6.12, U6.8, U7.12, U8.4
+5V: C7.1, C15.1, FB4.2, P1.9, P1.10, P6.9, P6.10, Q1.S, R1.2, R6.1, U3.2, U7.4
+12V: C4.1, D5.2, P1.3, P1.4, P2.2, P6.3, P6.4, Q7.S, R45.2, R48.1, RLY1.1, U2.1
-5.0V: C9.2, C19.1, IC2.4, IC3.4, L2.2, P1.15, P1.16, P6.15, P6.16, U6.4, U7.13, U8.11
/analog_board/1ch.L: P7.2, RLY1.6
/analog_board/1ch.R: P8.2, RLY1.11
/analog_board/2ch.L: P9.2, RLY1.8
/analog_board/2ch.R: P10.2, RLY1.9
/analog_board/EVOL_SCLK: P6.24, R15.1
/analog_board/EVOL_SDI: P6.28, R14.1
/analog_board/EVOL_~CS: P6.26, R13.1
/analog_board/INPUT_CH.L: P6.20, R33.2, U8.7
/analog_board/INPUT_CH.R: P6.22, R49.2, U8.14
/analog_board/INRASH_CURRENT_LIMITTER_GATE: P6.38, R41.2
/analog_board/LINE_OUT.L: J1.4, K4.3
/analog_board/LINE_OUT.R: J1.2, K3.3
/analog_board/MISO/MAIN_AMP_STANDBY: P6.32, R31.1
/analog_board/MOSI/EVOL_MUTE: P6.30, R16.1
/analog_board/SCK/MAIN_AMP_MUTE: P6.34, R32.1
/analog_board/SELECT_SOURCE_GATE: P6.36, R29.1
/mpu_board/ANALOG_PWR_GATE: IC1.11, R3.2
/mpu_board/EVOL_SCLK: IC1.14, P1.24
/mpu_board/EVOL_SDI: IC1.16, P1.28
/mpu_board/EVOL_~CS: IC1.15, P1.26
/mpu_board/I2C_SCL: IC1.28, P3.18, P4.18, R10.2, U4.7
/mpu_board/I2C_SDA: IC1.27, P3.16, P4.16, R9.2, U4.8, U4.9
/mpu_board/INPUT_CH.L: IC1.23, P1.20, ZD2.2
/mpu_board/INPUT_CH.R: IC1.24, P1.22, ZD1.2
/mpu_board/INPUT_SW: IC1.4, P3.20, P4.20, ROTENC1.S
/mpu_board/INRASH_CURRENT_LIMITTER_GATE: IC1.12, P1.38
/mpu_board/IR_RECEIVER: IC1.5, P3.26, P4.26, U5.1
/mpu_board/MISO/MAIN_AMP_STANDBY: IC1.18, P1.32, P3.8, P4.8, P5.1
/mpu_board/MOSI/EVOL_MUTE: IC1.17, P1.30, P3.12, P4.12, P5.4
/mpu_board/ROTARYENC_A: IC1.2, P3.22, P4.22, ROTENC1.A
/mpu_board/ROTARYENC_B: IC1.3, P3.24, P4.24, ROTENC1.B
/mpu_board/SCK/MAIN_AMP_MUTE: IC1.19, P1.34, P3.10, P4.10, P5.3
/mpu_board/SELECT_SOURCE_GATE: IC1.13, P1.36
/mpu_board/~DISPLAY_PWR_GATE: IC1.6, R7.2
/mpu_board/~RESET: IC1.1, P3.14, P4.14, P5.5, SW1.1
AGND: C5.2, C6.1, C8.2, C9.1, FB2.2, J1.1, K3.1, K4.1, P1.13, P1.14, P6.13, P6.14, P7.1, P8.1, P9.1, P10.1, R11.2, R12.1, R21.2, R22.2, R23.1, R24.1, R50.2, U7.10, U7.15, U8.3, U8.5, U8.10, U8.12
DGND: C1.2, C2.2, C3.2, C7.2, C10.2, C11.2, C12.2, C15.2, D2.2, FB5.2, IC1.8, IC1.22, IC4.2, IC5.2, P1.5, P1.6, P3.2, P4.2, P5.6, P6.5, P6.6, Q2.S, Q3.2, Q5.S, Q6.S, R2.2, R17.2, R30.2, R42.2, R50.1, ROTENC1.COM, SW1.2, U1.2, U3.3, U4.1, U4.3, U4.4, U5.2, U7.1, U7.5, ZD1.1, ZD2.1
GNDPWR: C4.2, C16.2, C17.2, C18.2, FB5.1, K5.1, P1.1, P1.2, P2.1, P6.1, P6.2, U2.2
LINE_IN_L: C14.2, U6.3, U7.16
LINE_IN_R: C13.2, U6.5, U7.9
unnamed: D1.1, R5.1
unnamed: P3.6, Q4.D
unnamed: FB4.1, U2.3
unnamed: Q4.G, R7.1, R8.1
unnamed: FB1.1, U1.6
unnamed: FB2.1, U1.5
unnamed: FB3.1, U1.4
unnamed: Q1.G, Q2.D, R1.1
unnamed: D2.1, R6.2
unnamed: C2.1, IC1.21
unnamed: C11.1, P4.6, U4.2
unnamed: Q1.D, U1.1
unnamed: IC1.10, Q3.3
unnamed: IC1.9, Q3.1
unnamed: C5.1, FB1.2, L1.1, R4.1, R5.2
unnamed: C6.2, D1.2, FB3.2, L2.1, R4.2
unnamed: Q2.G, R2.1, R3.1
unnamed: D6.2, R40.2, R43.1, U8.9
unnamed: R20.2, R25.2, R26.2, R33.1, U8.6
unnamed: IC4.1, R31.2
unnamed: D3.1, D4.2, U8.1
unnamed: R18.1, R20.1, U6.1, U6.2
unnamed: D3.2, R18.2, R19.1, U8.2
unnamed: D6.1, D7.2, U8.8
unnamed: R44.2, R46.2, R47.2, R49.1, U8.13
unnamed: C13.1, R11.1, RLY1.13
unnamed: C14.1, R12.2, RLY1.4
unnamed: R16.2, U7.8
unnamed: R15.2, U7.6
unnamed: R14.2, U7.3
unnamed: R13.2, U7.2
unnamed: Q6.D, Q7.G, R45.1
unnamed: R40.1, R44.1, U6.6, U6.7
unnamed: D5.1, Q5.D, RLY1.16
unnamed: R17.1, U7.7
unnamed: IC5.4, K2.1
unnamed: IC4.4, K1.1
unnamed: K1.3, R38.2
unnamed: K2.3, R39.2
unnamed: IC4.3, K1.2, R38.1
unnamed: IC5.3, K2.2, R39.1
unnamed: IC5.1, R32.2
unnamed: Q5.G, R29.2, R30.1
unnamed: D7.1, R43.2, R46.1, R47.1
unnamed: D4.1, R19.2, R25.1, R26.1
unnamed: IC2.7, IC3.5, R35.1
unnamed: IC2.5, R22.1, U7.14
unnamed: IC3.1, IC3.2, R36.1
unnamed: IC3.6, IC3.7, R37.1
unnamed: C16.1, C17.1, C18.1, K5.3, Q7.D, R48.2
unnamed: IC2.3, R21.1, U7.11
unnamed: J1.5, R28.2, R35.2, R37.2
unnamed: IC2.6, R24.2, R28.1
unnamed: IC2.1, IC3.3, R34.1
unnamed: J1.3, R27.2, R34.2, R36.2
unnamed: IC2.2, R23.2, R27.1
unnamed: Q6.G, R41.1, R42.1

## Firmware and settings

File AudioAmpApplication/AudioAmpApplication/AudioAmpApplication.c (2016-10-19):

/*
 * This software for IR control headphone amplifier main board Rev:A2.0 or above.
 * https://github.com/ak1211/IR-control-amp
 *
 * Copyright (c) 2015 Akihiro Yamamoto http://ak1211.com
 *
 * This software is released under the MIT License.
 * https://github.com/ak1211/IR-control-amp/blob/master/LICENSE
 */

/*
 * AudioAmpApplication.c
 * メインソースファイル
 *
 * Created: 2014/12/30 12:34:16
 *  Author: akihiro
 */

#include <stdbool.h>
#include <string.h>
#include <avr/io.h>
#include <avr/boot.h>
#include <avr/interrupt.h>
#include <avr/sleep.h>
#include <avr/power.h>
#include <avr/wdt.h>
#include <avr/eeprom.h>
#include <avr/pgmspace.h>
#include <util/delay.h>

#include "ApplicationIncl.h"
#include "IR_receiver.h"
#include "electric_volume.h"
#include "i2c_display.h"
#include "audio_level_meter.h"
#include "display.h"
#include "store_EEPROM.h"
#include "setup_menu.h"

//
// システム状態
//
typedef enum {
    DEEP_SLEEPING_STATE = 0,
    NORMAL_STATE,
    PENDING_SYSTEM_POWER_ON_STATE,
    PENDING_SYSTEM_POWER_OFF_STATE,
    INFO_DISP_STATE,
    MUTE_STATE,
    OMIT_DISPLAY_STATE,
    DEBUG_DISP_STATE,
} system_state_t;

//自動状態移行の間隔
#define STATE_SHIFT_PENDING_TIME    800


//
//システム変数
//
static struct {
    volatile int8_t         renc_rotation_travel;       //ロータリーエンコーダの移動量
    volatile uint64_t       input_switch_conditions;    //入力スイッチの状態検出用
             system_state_t system_state;               //システム状態
             int16_t        system_state_remain;        //システム状態移行残りカウンタ
             uint16_t       system_state_workspace;     //システム状態ワークスペース(各状態で好きなように)
             uint8_t        selected_source_number;     //選択中の入力源番号
             elevol_t       volume;                     //電子ボリュームの設定値
             audio_level_t  audio_level;                //オーディオ信号入力レベル
} SysVal = {
    .renc_rotation_travel = 0,
    .input_switch_conditions = 0,
    .system_state = NORMAL_STATE,
    .system_state_remain = 0,
    .system_state_workspace = 0,
    .selected_source_number = 0,
    .volume = 1,
    .audio_level = {},
};

//
//状態移行
//状態移行が発生したらtrueを返す
//
static bool switch_to_system_state( system_state_t next_state )
{
    SysVal.system_state_remain      = -1;                       //ダウンカウント停止
    SysVal.system_state_workspace   =  0;

    switch (next_state) {
        case MUTE_STATE: {
            if (SysVal.system_state == MUTE_STATE) {
                //ミュート状態はトグル動作です
                next_state = NORMAL_STATE;
            }
        } break;
        case OMIT_DISPLAY_STATE: {
            if (SysVal.system_state == OMIT_DISPLAY_STATE) {
                //表示省略状態はトグル動作です
                next_state = NORMAL_STATE;
            }
        } break;
        case INFO_DISP_STATE:
        case DEBUG_DISP_STATE:
            SysVal.system_state_remain = STATE_SHIFT_PENDING_TIME;  //ダウンカウント開始
        break;
        case DEEP_SLEEPING_STATE:
        case PENDING_SYSTEM_POWER_ON_STATE:
        case PENDING_SYSTEM_POWER_OFF_STATE:
        case NORMAL_STATE:
        break;
    }

    if (SysVal.system_state != next_state) {
        SysVal.system_state = next_state;
        return true;
    } else {
        return false;
    }
}

//
//状態管理用周期関数
//状態変化が発生したらtrueを返す
//
static bool periodic_func_of_system_state()
{
    bool retval = false;
    if (SysVal.system_state_remain == 0) {
        //カウント停止
        SysVal.system_state_remain = -1;
        //状態推移用ダウンカウント満了にて状態推移
        retval = switch_to_system_state (NORMAL_STATE);
    } else if (SysVal.system_state_remain > 0) {
        //正数の時カウントダウン
        SysVal.system_state_remain--;
    } else {
        //負数の時はカウント停止なので何もしない
    }

    return retval;
}

//
//デバッグ用情報表示
//即時表示してから状態移行で
//しばらく表示したままにする。
//
static inline bool DEBUG_MSG (const display_buffer_t buf)
{
    display_message(buf);
    return switch_to_system_state (DEBUG_DISP_STATE);
}

//
//ウォッチドッグタイマのリセットループ除けの設定
//
uint8_t mcusr_mirror __attribute__ ((section (".noinit")));
void get_mcusr(void) __attribute__((naked)) __attribute__((section(".init3")));
void get_mcusr(void)
{
    mcusr_mirror = MCUSR;
    MCUSR = 0;
    wdt_disable();
}

//
//ウォッチドッグタイマ利用のソフトウエアリセット
//
static void software_reset()
{
    display_clear();
    //ソフトウエアリセットフラグを立てておく
    EEPROM_set_software_reset_flag();
    wdt_enable(WDTO_15MS);
    do{}while(true);        //リセット待ちループ
}



//
//TIMER1割り込み開始
//このソフトウェアのステートマシンはこのタイマ割り込みに同期して動きます
//
static inline void timer1_start()
{
#if F_CPU == 8000000UL
    //
    //CTCモード (8分周 * (1+3599)) / 8MHz= 3.6ms
    //
    TCCR1A  = 0b00000000;
    TCCR1B  = 0b00001010;
    TIMSK1  = _BV(OCIE1A);  //比較Ａ割り込みを設定
    OCR1A   = 3599;
#else
#error "F_CPU is not valid"
#endif
}

//
// TIMER1割り込み終了
//
static inline void timer1_stop()
{
    TCCR1B = 0;
}

//
//ロータリーエンコーダ読み込み
//
static void capture_rotary_encoder()
{
    static uint8_t enc = 0;         //以前に呼ばれたときの値を保存する変数
    bool clockwise, anticlockwise;

    enc <<= 2;
    enc  |= (IOread_from_renc_A() <<1) | IOread_from_renc_B();

        clockwise = (enc >>2 &1) & (enc &1)  &   (enc >>3 &1) & (~enc >>1 &1);
    anticlockwise = (enc >>2 &1) & (enc &1)  &  (~enc >>3 &1) &  (enc >>1 &1);

    SysVal.renc_rotation_travel +=     clockwise;   //  時計回りで増加
    SysVal.renc_rotation_travel -= anticlockwise;   //反時計回りで減少
}

//
//num番の入力ソースへ切り替え
//
static uint8_t shift_to_num_audio_source( uint8_t num )
{
    if (num == 2) {
        SysVal.selected_source_number = 2;
        IOwrite_to_select_source_2();
        //LED表示処理
        IOwrite_to_red_green_blue_LED (0b010);  //入力２＝緑
    } else {
        SysVal.selected_source_number = 1;
        IOwrite_to_select_source_1();
        //LED表示処理
        IOwrite_to_red_green_blue_LED (0b001);  //入力１＝青
    }
    return SysVal.selected_source_number;
}

//
//次の入力ソースへ切り替え
//
static inline uint8_t shift_to_next_audio_source()
{
    return shift_to_num_audio_source( (SysVal.selected_source_number == 1) ? 2 : 1 );
}


//
//起動時アニメーションと突入電流抑制待ち
//
static void do_opening_animation_and_wait( bool isSetupMode )
{
    struct _message_text {
        char    ch;
        uint8_t pos;
    };
    static const struct _message_text default_message[] PROGMEM = {
        { 'H',  3 },
        { 'e',  5 },
        { 'l',  7 },
        { 'l',  9 },
        { 'o', 11 },
    };
    static const struct _message_text setup_mode_message[] PROGMEM = {
        { 'S',  1 },
        { 'e',  2 },
        { 't',  3 },
        { 'u',  4 },
        { 'p',  5 },
        { 'M',  7 },
        { 'o',  8 },
        { 'd',  9 },
        { 'e', 10 },
    };
    const struct _message_text  *message;
                        size_t  message_count;
    display_buffer_t buf = {};

    if (isSetupMode) {
        message         = setup_mode_message;
        message_count   = sizeof(setup_mode_message)/sizeof(setup_mode_message[0]);
    } else {
        message         = default_message;
        message_count   = sizeof(default_message)/sizeof(default_message[0]);
    }

    memset (buf[0].line, ' ', DISPLAY_WIDTH);
    memset (buf[1].line, ' ', DISPLAY_WIDTH);

    for (uint8_t idx=0 ; idx<message_count ; idx++) {
        char     ch = pgm_read_byte(&message[idx].ch);
        uint8_t pos = pgm_read_byte(&message[idx].pos);
        for (int8_t x=DISPLAY_WIDTH-2 ; x>=pos ; x--) {
            buf[0].line[x+0] = ch;
            buf[0].line[x+1] = ' ';
            display_message( buf );
        }
    }
    
    for (uint8_t idx=0 ; idx<60; idx++) {
        buf[0].line[12+0] =
        buf[0].line[12+1] =
        buf[0].line[12+2] =
        buf[0].line[12+3] = ' ';
        buf[0].line[12+(idx&3)] = '.';
        display_message( buf );
        _delay_ms(18);
    }
    buf[0].line[12+0] =
    buf[0].line[12+1] =
    buf[0].line[12+2] =
    buf[0].line[12+3] = ' ';

    for (uint8_t idx=0 ; idx<message_count ; idx++) {
        char     ch = pgm_read_byte(&message[idx].ch);
        uint8_t pos = pgm_read_byte(&message[idx].pos);
        //
        buf[0].line[pos] = ' ';
        for (int8_t x=pos ; x>=0 ; x--) {
            buf[1].line[x+0] = ch;
            buf[1].line[x+1] = ' ';
            display_message( buf );
        }
        buf[1].line[0] = ' ';
        display_message( buf );
    }
}

//
//終了時アニメーション
//
static void do_ending_animation_and_wait()
{
    //                                     1234567890123456
    static const char message[] PROGMEM = "    Goodbye.    ";
    display_buffer_t buf = {};
    int8_t x;

    memset (buf[0].line, ' ', DISPLAY_WIDTH);
    memset (buf[1].line, ' ', DISPLAY_WIDTH);

    display_clear();
    //
    //
    //
    for (x=0 ; x<=DISPLAY_WIDTH-2 ; x++) {
        buf[0].line[x+0] = pgm_read_byte(&message[x+0]);
        buf[0].line[x+1] = CHAR_LEFT_PEAK_LEVEL;
        display_message( buf );
    }
    for (uint8_t cnt=0 ; cnt<10 ; cnt++) {
        buf[0].line[x+0] = CHAR_LEFT_PEAK_LEVEL;
        display_message( buf );
        _delay_ms(120);
        buf[0].line[x+0] = ' ';
        display_message( buf );
        _delay_ms(120);
    }

    buf[0].line[x+0] = message[x+0];
    buf[1].line[x+0] = CHAR_LEFT_PEAK_LEVEL;
    display_message( buf );

    //
    //
    //
    for (x=DISPLAY_WIDTH-2 ; x>0 ; x--) {
        buf[1].line[x+0] = CHAR_LEFT_PEAK_LEVEL;
        buf[1].line[x+1] = ' ';
        display_message( buf );
    }
    buf[1].line[x+1] = ' ';

    for (int8_t period=1 ; period<7 ; period++) {
        //
        //
        //
        for (x=0+period ; x<=DISPLAY_WIDTH-2-period ; x++) {
            buf[0].line[x+0] = ' ';
            buf[0].line[x+1] = CHAR_LEFT_PEAK_LEVEL;
            display_message( buf );
        }
        buf[0].line[x+0] = ' ';
        buf[1].line[x+0] = CHAR_LEFT_PEAK_LEVEL;
        display_message( buf );
        //
        //
        //
        for (x=DISPLAY_WIDTH-2-period ; x>0+period ; x--) {
            buf[1].line[x+0] = CHAR_LEFT_PEAK_LEVEL;
            buf[1].line[x+1] = ' ';
            display_message( buf );
        }
        buf[1].line[x+1] = ' ';
    }
    display_message( buf );
}

//
// システム初期化
//
static void initialize()
{
    initialize_iopin();
    //突入電流抑制回路を有効にする。
    IOwrite_to_inrush_current_limitter_enable();
    //アナログ電源OFF
    IOwrite_to_analog_section_power_off();

    //オーディオレベルメーター初期化
    SysVal.audio_level = (audio_level_t){};

    i2c_display_init();

    //ADC
    ADCSRA = _BV(ADEN) | _BV(ADPS2) | _BV(ADPS1);
    ADMUX = 0x00;

    //
    //EEPROMより読み込む
    //
    EEPROM_read(&Saved_EEPROM_data);
    //EEPROMのデータを使う
    SysVal.volume = Saved_EEPROM_data.init_volume;

    //入力セレクタを設定
    shift_to_num_audio_source (SysVal.selected_source_number);

    //電子ボリュームを設定
    elevol_prepare ();
    SysVal.volume = elevol_setvolume (SysVal.volume);

    SysVal.system_state = NORMAL_STATE;
    switch_to_system_state(NORMAL_STATE);

    SysVal.renc_rotation_travel = 0;

    IRR_prepare();

    //
    // LレベルINT0割り込み
    //
    EICRA &= ~((1<<ISC01) | (1<<ISC00));

    //INT1の割り込み許可
    EIMSK |= (1<<INT1);
    //INT0の割り込み禁止
    EIMSK &= ~(1<<INT0);
}

//
// システム＆アンプ電源ON
//
static void system_power_on( bool isSetupMode )
{
    //INT0, INT1の割り込み禁止
    EIMSK &= ~((1<<INT1)|(1<<INT0));

    //突入電流抑制回路を有効にする。
    IOwrite_to_inrush_current_limitter_enable();
    //電源ON前にメインアンプをmute/standby状態にする
    //ポップノイズ防止のため
    IOwrite_to_main_amp_mute_mode_enable ();
    IOwrite_to_main_amp_stanby_mode_enable ();

    switch_to_system_state (INFO_DISP_STATE);

    display_prepare();
    //アナログ回路電源ON
    IOwrite_to_analog_section_power_on();
    _delay_ms(200);
    //突入電流抑制待ち時間中のアニメーション再生
    do_opening_animation_and_wait (isSetupMode);
    //突入電流抑制回路を無効にする。
    IOwrite_to_inrush_current_limitter_disable();

    elevol_prepare();

    //以前の状況に復帰
    SysVal.selected_source_number =
        shift_to_num_audio_source (SysVal.selected_source_number);
    SysVal.volume = elevol_setvolume(SysVal.volume);

    //メインアンプのmute/standby状態を解除する
    IOwrite_to_main_amp_stanby_mode_disable ();
    IOwrite_to_main_amp_mute_mode_disable ();

    //TIMER1起動
    timer1_start();

    //INT1の割り込み許可
    EIMSK |= (1<<INT1);
    //INT0の割り込み禁止
    EIMSK &= ~(1<<INT0);
}

//
// システム＆アンプ電源OFF
//
static void system_power_off()
{
    //TIMER1停止
    timer1_stop();

    //INT0, INT1の割り込み禁止
    EIMSK &= ~((1<<INT1)|(1<<INT0));

    //電源OFF前にアンプをmute/standby状態にする
    //ポップノイズ防止のため
    IOwrite_to_main_amp_mute_mode_enable ();
    IOwrite_to_main_amp_stanby_mode_enable ();

    do_ending_animation_and_wait();

    //アナログ回路電源OFF
    IOwrite_to_analog_section_power_off();

    elevol_power_save();
    display_power_save ();

    //アンプソースを強制的にチャネル１へ(リレーコイルの励磁電流を切る)
    IOwrite_to_select_source_1();

    //復帰時に余計な変数をクリア
    SysVal.renc_rotation_travel = 0;
    SysVal.input_switch_conditions = 0;
    //
    //リモコンでONするためにここで初期化する
    //
    IRR_prepare();

    switch_to_system_state (DEEP_SLEEPING_STATE);

    //LEDも省エネのためにOFF
    IOwrite_to_red_green_blue_LED(0b000);
    //フォトカプラも省エネのためにOFF
    IOwrite_to_main_amp_stanby_mode_pwrsave();
    IOwrite_to_main_amp_mute_mode_pwrsave();

    //
    //割り込みに使用するピンがHレベルになるまで待つ
    //
    do{}while (IOread_from_input_switch() | IOread_from_IR_receiver());

    //割り込みでスリープ解除のため
    //INT0の割り込み許可
    EIMSK |= (1<<INT0);
    //INT1の割り込み許可
    EIMSK |= (1<<INT1);
    //
    //スリープ
    //スタンバイモード(クロック発振を止めないモード)を設定
    //
    set_sleep_mode(SLEEP_MODE_STANDBY);
    sleep_mode();
}

//
//タイマ1割り込みベクタ
//
ISR(TIMER1_COMPA_vect)
{
    static uint8_t division_counter = 0;    //分周用
    
    //
    //オーディオレベル取り込み
    //
    periodic_capture_audio_level (&SysVal.audio_level);

    //ロータリーエンコーダ読み込み
    capture_rotary_encoder();
    //分周カウンタのカウント
    division_counter = (division_counter + 1) & 15; // 1/16分周
    //分周カウンタのカウント満了毎で読み込む
    if (division_counter == 0) {
        //入力スイッチ読み込み
        SysVal.input_switch_conditions = (SysVal.input_switch_conditions << 1) | (IOread_from_input_switch() & 1);
    }
}

//
//INT0割り込みベクタ
//入力スイッチ押下げ割り込みはスリープ復帰のトリガー
//
ISR(INT0_vect)
{
    IOwrite_to_red_green_blue_LED(0b100);
    //スイッチが離されるまで待つ
    do{}while (IOread_from_input_switch());
    switch_to_system_state (PENDING_SYSTEM_POWER_ON_STATE);

    //INT0の割り込み禁止
    EIMSK &= ~(1<<INT0);
}

//
//リモコン入力に反応する
//状態移行が発生したらtrueを返す
//
static bool react_to_remocon_input( IRR_frame_t *frame )
{
    bool retval = false;
    
    if (frame->type == ERROR) {
        return false;
    }

    //リモコンコードの確認
    switch (get_ircode_mapping(&frame->u))
    {
        //電源ON/OFF
        case IRCODE_onoff: {
            retval = switch_to_system_state (PENDING_SYSTEM_POWER_OFF_STATE);
            //repeat無効にする
            frame->u.ir.data_code = 0x00;
        } break;
        //入力切替
        case IRCODE_switch_source: {
            shift_to_next_audio_source();
            //repeat無効にする
            frame->u.ir.data_code = 0x00;
            //変化を表示する
            retval = switch_to_system_state (INFO_DISP_STATE);
        } break;
        //音量＋
        case IRCODE_volume_up: {
            SysVal.volume = elevol_setvolume(SysVal.volume+1);
            //変化を表示する
            retval = switch_to_system_state (INFO_DISP_STATE);
        } break;
        //音量ー
        case IRCODE_volume_down: {
            SysVal.volume = elevol_setvolume(SysVal.volume-1);
            //変化を表示する
            retval = switch_to_system_state (INFO_DISP_STATE);
        } break;
        //ミュート
        case IRCODE_mute: {
            retval = switch_to_system_state (MUTE_STATE);
            //repeat無効にする
            frame->u.ir.data_code = 0x00;
        } break;
        //表示省略
        case IRCODE_omit_display: {
            retval = switch_to_system_state (OMIT_DISPLAY_STATE);
            //repeat無効にする
            frame->u.ir.data_code = 0x00;
        } break;
        //その他
        case IRCODE_total_num :
        case IRCODE_not_found : break;
    }

    return retval;
}
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
int main()
{
    bool isSetupMode = false;

    //初期化
    initialize ();

    //
    //リセット要因の確認をする
    //
    if (bit_is_set(mcusr_mirror, BORF)) {
        //ブラウンアウトリセットであった
        EEPROM_acc_brownout_reset_counter();
    }
    if (bit_is_set(mcusr_mirror, WDRF)) {
        //ウォッチドッグ・システム・リセットであった
        if (!EEPROM_get_software_reset_flag()) {
            //ウォッチドッグ・タイムアウトリセットカウンタを加算する
            EEPROM_acc_watchdog_timeout_counter();
        }
    }
    //ソフトウエアリセットフラグをクリアしておく
    EEPROM_clear_software_reset_flag();
    //
    //ここで(リセット直後)入力スイッチが押されたままであったら、
    //システム設定に移行する
    //
    if (IOread_from_input_switch()) {
        isSetupMode = true;
    }

    //電源投入時は初期化後にON状態に移行
    system_power_on(isSetupMode);

    sei();  //割り込み開始

    if (isSetupMode) {
        //
        //システム設定
        //
        display_buffer_t display_buf;
        memset (display_buf, ' ', sizeof(display_buffer_t));
        //システム設定へ
        system_setup( display_buf, 0, &top_setup_menu, NULL, FIRST_MENU_ITEM );
        //ここでリセット
        software_reset();
    }

    //
    //ウォッチドッグタイマーを有効にする
    //
#define WDT_ENABLE()    wdt_enable(WDTO_30MS)
    WDT_ENABLE();
    //
    //メインループ
    //
    for(;;) {
        //状態推移用周期関数呼び出し
        periodic_func_of_system_state();
        //
        //ステートマシンの状態によって
        //それぞれの処理をする
        //
        switch (SysVal.system_state)
        {
            //
            case DEEP_SLEEPING_STATE: {
                //
                //システムOFF中の呼び出し
                //入力スイッチ、赤外線リモコンのLレベル割り込みでスリープからの復帰をするが、
                //入力スイッチ割り込みはその割り込みハンドラ内でPOWER ON待機状態に移行するために
                //赤外線リモコン割り込み発生時のみここに来る。
                //
                IRR_frame_t frame = {0};
                IOwrite_to_red_green_blue_LED(0b100);
                if (is_power_onoff_remocon_frame_block (&frame)) {
                    switch_to_system_state (PENDING_SYSTEM_POWER_ON_STATE);
                } else {
                    IOwrite_to_red_green_blue_LED(0b000);
                    _delay_ms(1);
                    if (IRR_getCaptureCondition() == IRR_CAPTURE_IDLE) {
                        switch_to_system_state (PENDING_SYSTEM_POWER_OFF_STATE);
                    }
                }
            } continue; //ループの先頭へ
            //
            case PENDING_SYSTEM_POWER_ON_STATE: {
                //
                //system power ON待機状態のためにここでPOWER ON
                //
                system_power_on(false);
                //
                //スリープ復帰後ウォッチドッグタイマーを有効にする
                //
                WDT_ENABLE();
            } continue; //ループの先頭へ
            //
            case PENDING_SYSTEM_POWER_OFF_STATE: {
                //
                //スリープ中はウォッチドッグタイマーを無効にする
                //
                wdt_disable();
                //
                //system power OFF待機状態のためにここでPOWER OFF
                //
                system_power_off();
            } continue; //ループの先頭へ
            //
            case MUTE_STATE: {
                //
                //ミュート状態
                //
                elevol_set_mute();
                //外部入力に反応する
                bool isShiftState = react_to_external_input();
                //情報を表示する
                SysVal.system_state_workspace = display_mute_information (SysVal.system_state_workspace, SysVal.volume);
                if (isShiftState) {
                    //状態変化前にミュート解除
                    elevol_clear_mute(SysVal.volume);
                }
            } break;
            //
            case OMIT_DISPLAY_STATE: {
                //
                //表示省略状態
                //
                //ディスプレイをOFFする
                display_power_save();
                //外部入力に反応する
                bool isShiftState = react_to_external_input();
                if (isShiftState) {
                    //
                    //時間のかかる処理なので、一旦ウォッチドッグタイマーを無効にする
                    //
                    wdt_disable();
                    //状態変化前にディスプレイをONする
                    display_prepare();
                    //
                    //ウォッチドッグタイマーを有効にする
                    //
                    WDT_ENABLE();
                }
            } break;
            //
            case DEBUG_DISP_STATE: {
                //
                //デバッグ情報表示状態
                //情報表示はすでに行われているので
                //ここでは何もしない
                //
                //外部入力に反応する
                react_to_external_input();
            } break;
            //
            case INFO_DISP_STATE: {
                //
                //情報表示状態
                //
                //外部入力に反応する
                react_to_external_input();
                //情報を表示する
                display_information (SysVal.volume);
            } break;
            //
            case NORMAL_STATE: {
                //
                //通常状態
                //
                //レベルメーターを表示する
                display_audio_level_meter (&SysVal.audio_level);
                //外部入力に反応する
                react_to_external_input();
            } break;
        }
        //
        //タスク処理終了後
        //アイドルモードでスリープ
        //赤外線リモコン割り込み、タイマ割り込み等があるまで
        //ここで停止する
        //
        set_sleep_mode(SLEEP_MODE_IDLE);
        sleep_mode();
        //
        //ウォッチドッグタイマーをリセットする
        //
        wdt_reset();
    }
}

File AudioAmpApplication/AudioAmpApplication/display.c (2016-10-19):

/*
 * This software for IR control headphone amplifier main board Rev:A2.0 or above.
 * https://github.com/ak1211/IR-control-amp
 *
 * Copyright (c) 2015 Akihiro Yamamoto http://ak1211.com
 *
 * This software is released under the MIT License.
 * https://github.com/ak1211/IR-control-amp/blob/master/LICENSE
 */

/*
 * display.c
 * ディスプレイに表示する部分を担当します。
 *
 * Created: 2015/04/22 20:43:15
 *  Author: akihiro
 */

#include <stdio.h>
#include <stdbool.h>
#include <avr/io.h>
#include <avr/pgmspace.h>
#include <string.h>

#include "ApplicationIncl.h"
#include "electric_volume.h"
#include "audio_level_meter.h"
#include "i2c_display.h"
#include "display.h"

//ミュートメッセージのウエイト
#define MUTE_MESSAGE_SCROLL_WAIT    200

//今のディスプレイバッファ
static display_buffer_t nowDisplayBuffer = {};
//次のディスプレイバッファ
static display_buffer_t nextDisplayBuffer = {};

enum {
    LEVEL_METER_TABLE_SIZE = 30,
    LEVEL_METER_SCALE_MIN = 0,
    LEVEL_METER_SCALE_MAX = LEVEL_METER_TABLE_SIZE-1,
};
static int8_t num_of_bar_level( uint16_t level, int8_t level_over_return )
{
    static const uint16_t level_meter_tbl[LEVEL_METER_TABLE_SIZE] PROGMEM = {
        //最大値 +3vu
          1,   2,   3,   6,   9,  13,  20,  30,  38,  47,  60,  76,  85,  95, 107,
        120, 135, 151, 170, 191, 214, 240, 269, 302, 320, 339, 359, 381, 452, 538,
    };

    for (uint8_t idx=0 ; idx<LEVEL_METER_TABLE_SIZE ; idx++) {
        if (level < pgm_read_word(&level_meter_tbl[idx])) {
            return idx;
        }
    }
    return level_over_return;   //レベルオーバー
}

//
//現在のボリュームをメーターの形で表現
//
static void render_volume_meter( display_line_buf_t line, elevol_t volume )
{
    volume = elevol_validate_volume( volume );
    //バックグラウンド
    memset (line, CHAR_VOL_BACKGROUND, DISPLAY_WIDTH );
    //指針を書き込む
    uint8_t idx = volume >> 1;
    line[idx] = (volume & 1) ? CHAR_VOL_RIGHT_BAR : CHAR_VOL_LEFT_BAR;
}

//
//現在の入力とボリューム
//
static void render_input_source_and_volume( display_line_buf_t line, uint8_t src_num,  elevol_t volume )
{
    char buf[DISPLAY_WIDTH + 1];
    snprintf_P (buf, sizeof(buf), PSTR("SOURCE:%-3dVOL:%2d"),  src_num, volume);
    strncpy (line, buf, DISPLAY_WIDTH );
}

//
//オーディオレベルメータ表示
//
static void render_audio_level_meter( audio_level_t* audiolevel )
{
    const char msg[] = "LR";

    for (uint8_t linenum=0 ; linenum<DISPLAY_LINES ; linenum++) {
        //
        union UU16LeftRight al, pl;
        get_audio_level( &al, &pl, audiolevel );
        //オーディオレベルからメーターの位置を得る
        int8_t level = num_of_bar_level( al.array[linenum], LEVEL_METER_SCALE_MAX );
        //ピークレベルからメーターの位置を得る
        int8_t peak = num_of_bar_level( pl.array[linenum], LEVEL_METER_SCALE_MAX );
        //
        //メータの位置を画面に表示する
        //
        int8_t idx = DISPLAY_WIDTH - 1;
        //
        memset (nextDisplayBuffer[linenum].line, ' ', DISPLAY_WIDTH);
        //'L'または'R'を表示する
        nextDisplayBuffer[linenum].line[0] = msg[linenum];
        if (level > 0) {
            //レベル位置のレベルメーターキャラクタ書き込み
            idx = 1 + (level >> 1); //0の位置はLまたはR文字がいるため1から開始
            if ((level & 1) == 0) {
                //２の倍数なら左右表示
                nextDisplayBuffer[linenum].line[idx] = CHAR_LEFT_RIGHT_BAR;
                idx--;
            } else {
                //２の倍数でないなら左表示
                nextDisplayBuffer[linenum].line[idx] = CHAR_LEFT_BAR;
                idx--;
            }
            //レベル位置のレベルメーターキャラクタより下は左右表示
            for (; idx>=1 ; idx--) {
                //左右表示
                nextDisplayBuffer[linenum].line[idx] = CHAR_LEFT_RIGHT_BAR;
            }
        }
        //ピークレベル位置キャラクタ書き込み
        idx = 1 + (peak >> 1);  //0の位置はLまたはR文字がいるために1から開始
        if (peak > 0) {
            idx = idx + 1;      //ピークキャラクタはレベルメーターの右側
        }
        if (idx >= DISPLAY_WIDTH) {
            //over dB
            nextDisplayBuffer[linenum].line[DISPLAY_WIDTH-1] = CHAR_PEAK_LEVEL_OVER_DB;
        } else {
            if ((peak & 1) == 0) {
                //２の倍数なら左表示
                nextDisplayBuffer[linenum].line[idx] = CHAR_LEFT_PEAK_LEVEL;
            } else {
                //２の倍数でないなら右表示
                nextDisplayBuffer[linenum].line[idx] = CHAR_RIGHT_PEAK_LEVEL;
            }
        }
    }
}

//
//全ての文字を更新する
//
static void show_display_force()
{
    for (int8_t linenum=0 ; linenum<DISPLAY_LINES ; linenum++) {
        for (int8_t column=0 ; column<DISPLAY_WIDTH ; column++) {
            //カーソルを移動
            i2c_display_send_command (0x80 + 0x20*linenum + column);
            //更新
            nowDisplayBuffer[linenum].line[column] = nextDisplayBuffer[linenum].line[column];
            i2c_display_send_data (nowDisplayBuffer[linenum].line[column]);
        }
    }
}

//
//バッファと比較して、変化のあった部分だけ更新する
//
static void update_display()
{
    for (int8_t linenum=0 ; linenum<DISPLAY_LINES ; linenum++) {
        for (int8_t column=0 ; column<DISPLAY_WIDTH ; column++) {
            if (nowDisplayBuffer[linenum].line[column] != nextDisplayBuffer[linenum].line[column]) {
                //カーソルを移動
                i2c_display_send_command (0x80 + 0x20*linenum + column);
                //更新
                nowDisplayBuffer[linenum].line[column] = nextDisplayBuffer[linenum].line[column];
                i2c_display_send_data (nowDisplayBuffer[linenum].line[column]);
            }
        }
    }
}

//
//ディスプレイに表示する。
//
void display_message( const display_buffer_t buffer )
{
    for (uint8_t linenum=0 ; linenum<DISPLAY_LINES ; linenum++) {
        //行
        int8_t column;
        for (column=0 ; (column<DISPLAY_WIDTH)&&(buffer[linenum].line[column] != '\0') ; column++) {
            //桁
            nextDisplayBuffer[linenum].line[column] = buffer[linenum].line[column];
        }
        //'\0'以降は空白で表示する
        for (; column<DISPLAY_WIDTH ; column++) {
            nextDisplayBuffer[linenum].line[column] = ' ';
        }
    }

    show_display_force();
}

//
//情報を表示する。
//
void display_information( elevol_t volume )
{
    //１行目
    render_volume_meter( nextDisplayBuffer[0].line, volume );
    //２行目
    render_input_source_and_volume( nextDisplayBuffer[1].line, IOread_from_select_source(), volume );

    update_display ();
}

//
//ミュート状態の情報を表示する。
//
uint16_t display_mute_information( uint16_t counter, elevol_t volume )
{
    static const char message[] PROGMEM = {
    //   1234567890123456
        "   M  u  t  e   "
        "   m  U  t  e   "
        "   m  u  T  e   "
        "   m  u  t  E   "
    };
    #if MUTE_MESSAGE_SCROLL_WAIT <= 0
    #error "MUTE_MESSAGE_SCROLL_WAIT must be natural number"
    #endif
    //１行目
    uint8_t idx = (counter / (MUTE_MESSAGE_SCROLL_WAIT)) % 4;
    strncpy_P (nextDisplayBuffer[0].line, &message[16*idx], DISPLAY_WIDTH );
    //２行目
    render_input_source_and_volume( nextDisplayBuffer[1].line, IOread_from_select_source(), volume );

    update_display ();

    return (counter + 1) % (MUTE_MESSAGE_SCROLL_WAIT*4);
}
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

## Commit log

2016-02-25 2乗計算をループの外にした
2016-09-13 add KiCad project files
    [.kicad_pcb.kicad_pcb, analog_section.sch, audio_amp-BOM.csv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]
2016-09-13 first add KiCad project file
2016-10-19 fix the MIT license notation
    [AudioAmpApplication.c, audio_level_meter.c, display.c]

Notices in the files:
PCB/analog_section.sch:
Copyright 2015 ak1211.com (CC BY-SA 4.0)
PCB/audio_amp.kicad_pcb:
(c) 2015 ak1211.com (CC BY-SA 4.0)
